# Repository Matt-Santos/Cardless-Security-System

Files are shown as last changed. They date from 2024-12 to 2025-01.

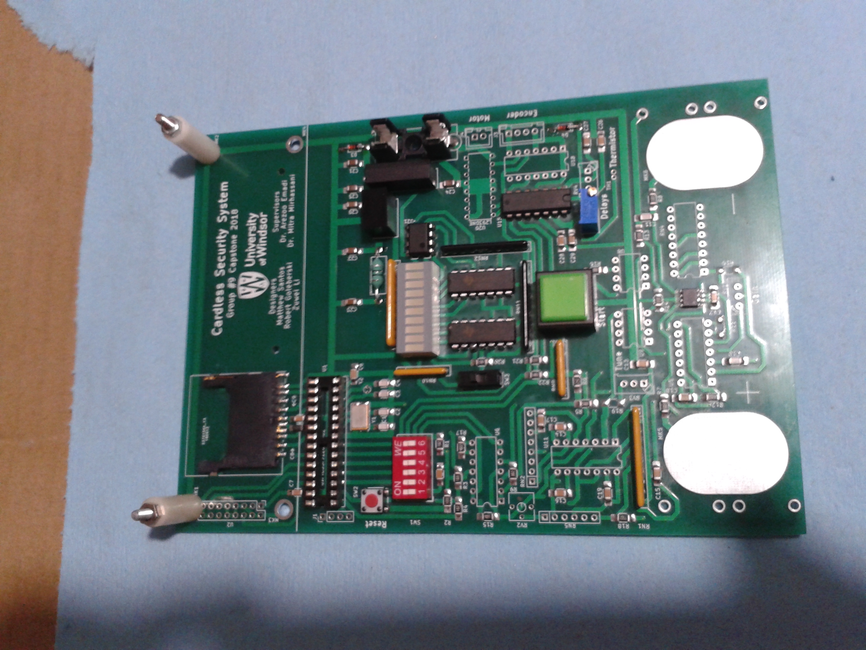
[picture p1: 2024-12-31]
documents/images/gallery/Partial Assembly 2.jpg

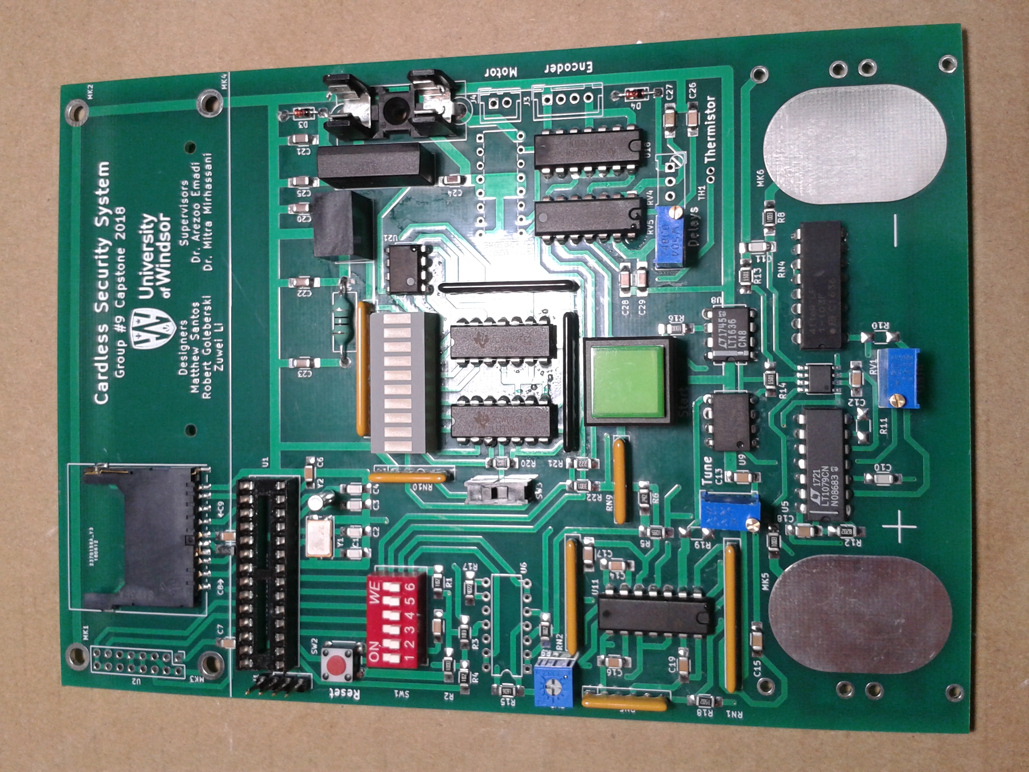
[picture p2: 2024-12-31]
documents/images/gallery/Partial Assembly.jpg

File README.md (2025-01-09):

# Cardless Security System
***
## Project Description
A **cardless security system** based on human **electro cardiogram (ECG) biometrics** that will be able to identify specified individuals, assess their authorization privileges and subsequently permit or deny access to
restricted areas. The entry regulation method is a custom designed electronic door locking
mechanism. Device is includes additional security features to prevent unauthorized entry. The unit
itself is battery operated with audio and visual indicators used to denote various system states.

## Goals and Objectives
1) Differentiate between individuals based on personal ECG signals
2) A secure mechanical locking system driven by an electric motor
## Brief Background
Most biometric identification devices currently in use throughout the world rely on either facial,
fingerprint, retina, or voice recognition systems. All of these authentication methods have been shown to
produce unique signatures that remain relatively consistent over time and are difficult to emulate with
the notable exception of voice based systems. Although obviously less secure the appeal of audio
biometric systems is driven primarily by its substantially lower implementation costs as opposed to the
other metrics which require sophisticated vision hardware. This desire for inexpensive biometric devices
has driven the search for alternative unique human signatures. Over the last few years electrocardiogram
(ECG) based recognition has shown potential. One of the advantages of this metric include the fact it is
an internal signal which is highly subject to personal health and mental state and is thus difficult to
procure from unwilling or deceased individuals. It is also fairly inexpensive to both capture and process
the ECG signals leading to a very high overall desirability. Research into this field is still being
conducted and very few viable commercial products are currently available.

## Final Result
An enclosed printed circuit board mounted alongside a custom electronic door locking mechanism.
The board is to include a built-in ECG acquisition system, audio and visual status indicators, as well as
the internal processing power required to perform biometric identification.

## Timeline
See [Gantt Chart](/documents/reports/Proposal/ProjectSchedule.pdf)

# Software Listing
* Git
* KiCAD
* GanttProject
* Latex (MiKTeX)
* Matlab (Octave)
* LTSpice

# Team Members
* Matthew Santos
* Robert Goleberski
* Zuwei Li
# Supervisors
* Dr. Emadi
* Dr. Mirhassani

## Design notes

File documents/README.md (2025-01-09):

This cardless security system leverages human electrocardiogram (ECG) biometrics for authentication. It features an integrated printed circuit board (PCB) paired with a custom electronic door locking mechanism. The PCB houses an ECG acquisition system, audio/visual status indicators, and sufficient processing power to perform biometric identification. When an ECG credential is submitted, the system extracts 27 distinct fingerprint variables from the signal. These variables are then processed by a support vector machine (SVM) to generate a score that indicates the similarity between the submitted ECG and the authenticated user's ECG data. The SVM is trained on a comprehensive database of ECG signals, with system reliability being highly dependent on the quality and quantity of the training data used.

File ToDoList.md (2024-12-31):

# Overall Progress:
## General
- [x] Assemble group and discus the project
- [x] Get the project approved
- [x] Generate Block Schematic
- [x] Power Circuit
- [x] Sensor Circuit
- [x] MPU Circuit
- [x] Signal Processing Code
- [x] Design Overall Circuit Schematic
- [x] Complete the Progress Report
- [x] Prepare Progress Report Presentation
- [x] Decide on Parts and Perform Layout
- [x] Build the Prototype
- [x] Test the Prototype
- [x] Complete the Final Report
- [x] Finalize Project Presentation
## Simulation Work (Matlab/Octave)
- [x] Obtain Small Library of Sample Data
- [x] Create Script to Perform Initial Filtering (Preprocessing)
- [x] Create Script to Perform Feature Extraction
- [x] Create Script for Biometric Support Vector Machine
## Digital Signal Processing
- [x] Determine Resolution and Sample Rate
- [x] Design the Preprocessing Filters
- [x] Design the Feature Extraction Transfer Functions
- [x] Realize All DSP Filters
- [x] Integrate Into MicroController
## MicroController Programing
- [x] Configure Setup
- [x] Setup Start Button Trigger
- [x] Setup ADC Sampling
- [x] Create Interrupt Routines
- [x] Write Preprocessing Procedure
- [x] Write Feature Extraction Procedure/Code
- [x] Write Support Vector Machine
- [x] Write Authorize Output Trigger
- [x] Create Functions for LCD Control
- [x] Create Functions for SD-Card Control
- [x] Add LCD Functionality
- [x] Add SD-Card Functionality
- [ ] Convert Key Variables to SD-Card Reads (Externalize Control)

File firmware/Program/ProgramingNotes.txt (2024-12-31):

//Important MPU Notes for Report

//General Details
- MPU setup to run at 40MHz through use of a PLL
- Uses a Status Register to Monitor Progress
- Currently Using Fixed Point Arithmetic!
- Takes approximately 6 cycles (150ns) per fractional multiplication

//ADC1 Setup
- Uses Simultaneous Sampling
- Uses DMA for quick transferring to SRAM
- Conversion Triggered by Timer3 Compare Event
- Data Transfered in a Ping-Pong Mode with Two alternating Output Buffers
- Measurement Accuracy is 10bit giving +/- 3mV at [0V,3V] limits
- SampleRate is Easily Adjustable between 10Hz and 625kHz
- Temperature is currently only sampled once per DMA block

//Temperature Averaging
- Performed using the DSP Engine
- Calculation accuracy of +/- 0.04mV
- Each Sample Takes 10 cycles (250ns) to process

//Preprocessing Setup
-

//Notes for Report
- Greatest Challenge: (Conversion to Fixed Point Arithmetic)
    - You see in Matlab/Octave you have a supercomputer so you just use floats for everything
    the problem is that float math is really slow on a microcontroller and it was not until
    after I designed the algorithm that I realized this. I essentially had to rip apart large
    sections and completely redesign them using one of the most confusing data types I have had
    the horror of working with ... Fixed point math...

//Things to do Before Trying on Chip Itself
- uncomment sleep and remove forced start button press
- uncomment delay after start button press
- Ensure SampleRate = 500
- Set ECGLength = 2560
- Set DMA0BufferSize = 32

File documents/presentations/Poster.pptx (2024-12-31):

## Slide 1

Cardless Security System
Using Electrocardiogram Biometric Identification
Faculty of Engineering Dept. Electrical and Computer Engineering
Group 9 – Zuwei Li, Matthew Santos, Robert Goleberski
Advisors: Dr. Arezoo Emadi, Dr. Mitra Mirhassani
Capstone Project 2018

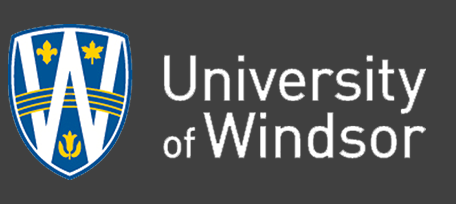
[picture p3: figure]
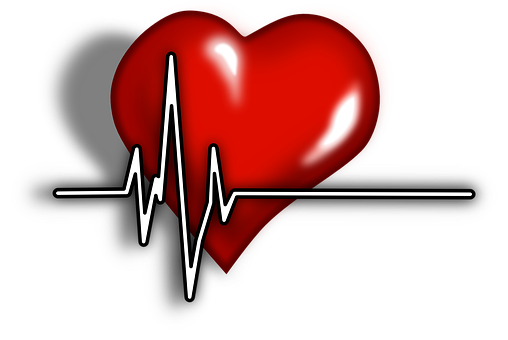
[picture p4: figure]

Final Prototype

Motivation

Current methods of biometric identification include voice analysis, retina scans, face recognition and the widely popular fingerprint system. The current success of the fingerprint method is owed to its compromise between the level of security offered and the cost of implementation. The remaining methods are still applicable however they generally lean towards either extreme and thus remain niche markets. There is however a new contender entering the industry which also offers a balanced approach. This new system which is still undergoing research, utilizes the measurement of the internal heart signal through an electrocardiogram in an attempt to distinguish individuals. Being an internal signal offers a wide array of benefits including reduced public exposure as well as the inability to modify the access token. Results continue to look promising however there are still many obstacles to overcome before it becomes the new standard.

Biometric Algorithm

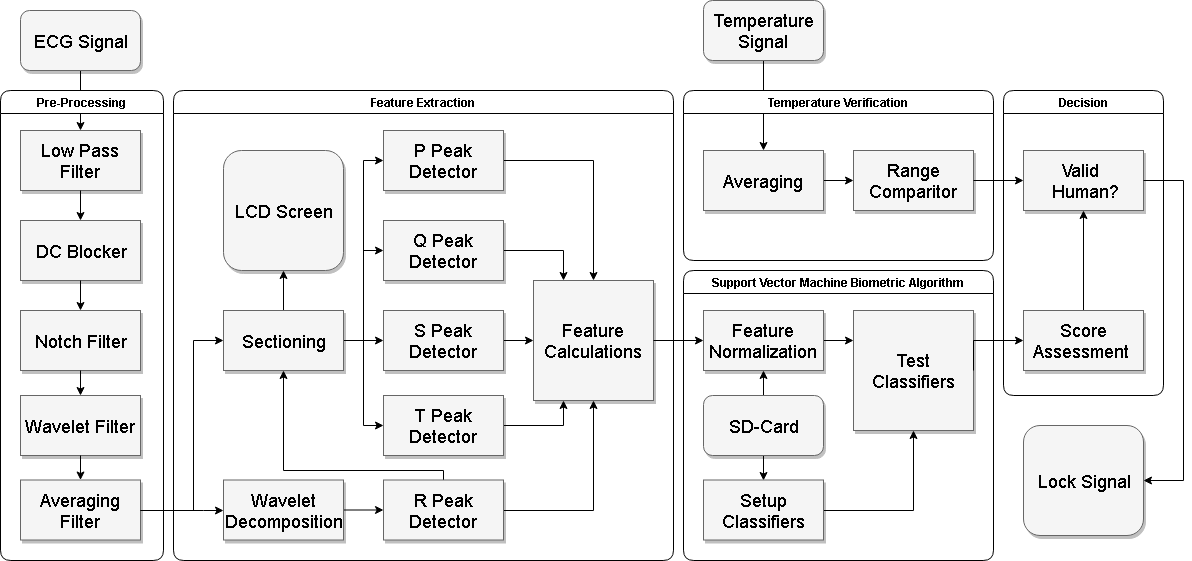
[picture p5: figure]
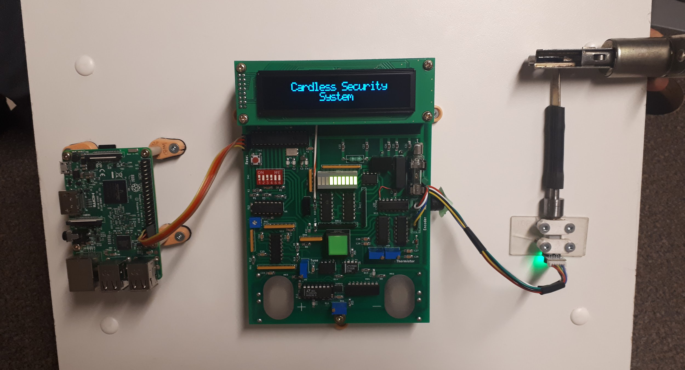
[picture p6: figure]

Experiment Results

Introduction

The aim of this project was to develop a cardless security system based on the principle of ECG biometrics. To facilitate future investments in the field the project was tailored towards the development of a marketable product. In order to accomplish this a more unobtrusive method for ECG acquisition was required as the standard 12 lead system is impractical for everyday use. Instead a two finger based ECG measurement system was proposed using inexpensive dry contact electrodes. As this measurement methodology degrades signal quality the analysis procedure had to be heavily refined through the use of onboard digital signal processing. The biometric algorithm itself also had to be constructed from scratch and was centered around the use of machine learning, more specifically support vector machines. After being processed the resulting biometric determination is then used in conjunction with information gathered from a secondary temperature sensor in order further validate the individual as human and actuate the locking mechanism.

System Requirements

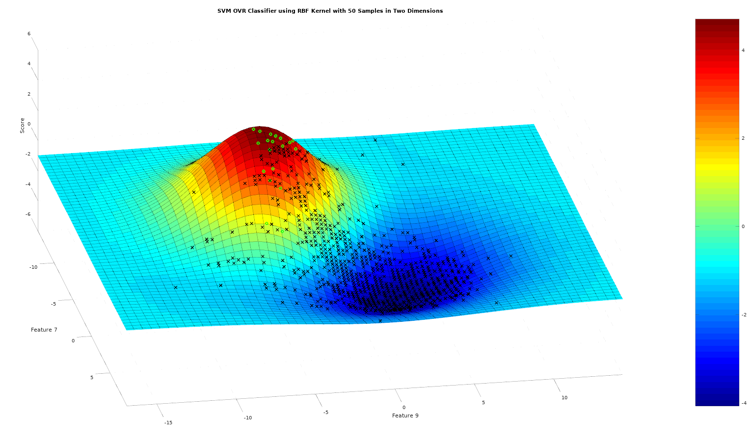
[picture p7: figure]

System Architecture

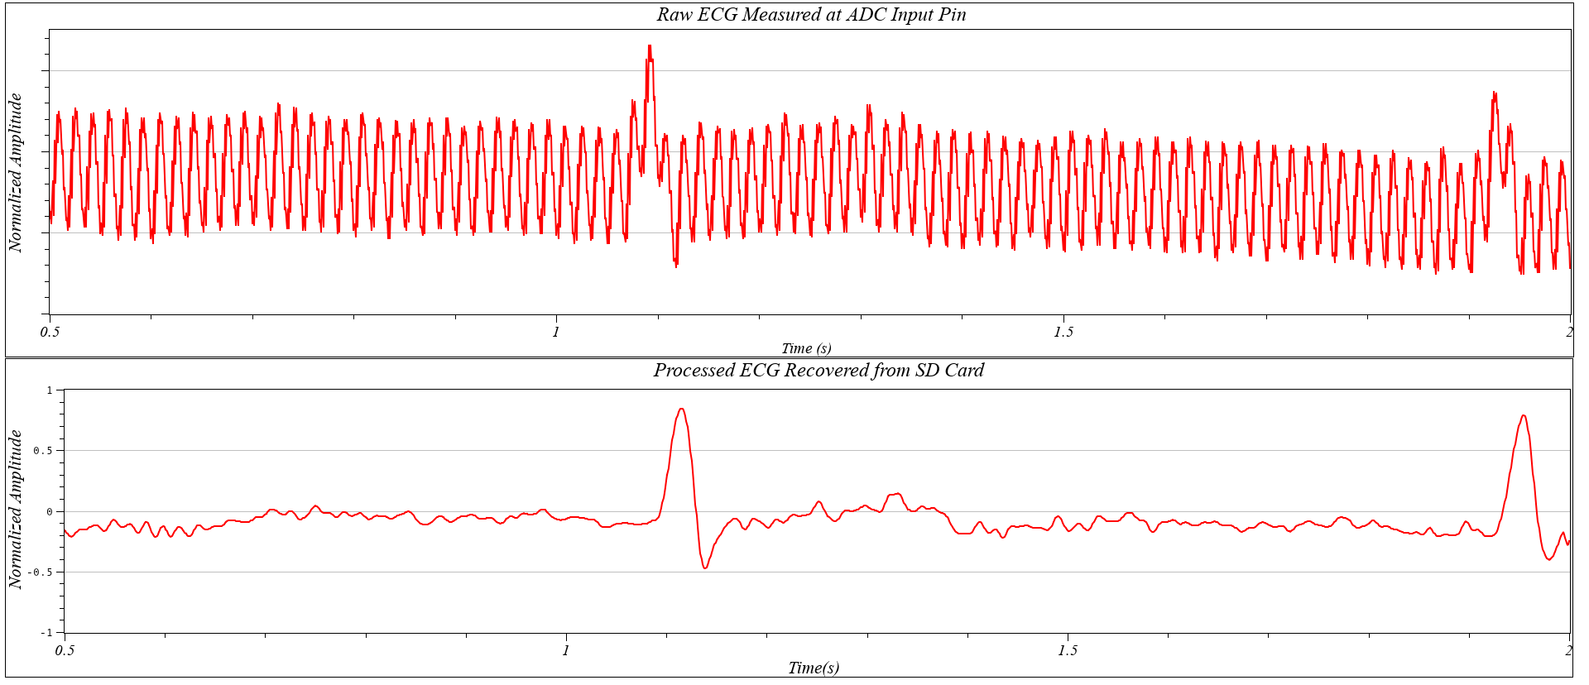
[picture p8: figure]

Future Work

- Continue to refine the biometric algorithm to improve accuracy
- Transition to a surface mount design for smaller form factor
- Perform a research study to accurately determine success rate

Acknowledgements

- Supervisors: Dr. Arezoo Emadi & Dr. Mitra Mirhassani
- Special Thanks: Frank Cichello, Dr. Behnam Shahrrava,

- System must differentiate between individuals based on electrocardiogram signals
- A completely embedded design with a black box emphasis for added security
- Incorporate a secure mechanical locking system driven by an electric motor
- An affordable solution, specifically an initial prototype budget of less than $350
- Present audio and visual indicators regarding the status of execution

References

- Lourenco, Andre & Plácido da Silva, Hugo & Santos, Daniel & Fred, Ana. (2011). Towards a Finger based ECG Biometric System
- Lugovaya T.S. (2005). Biometric human identification based on electrocardiogram

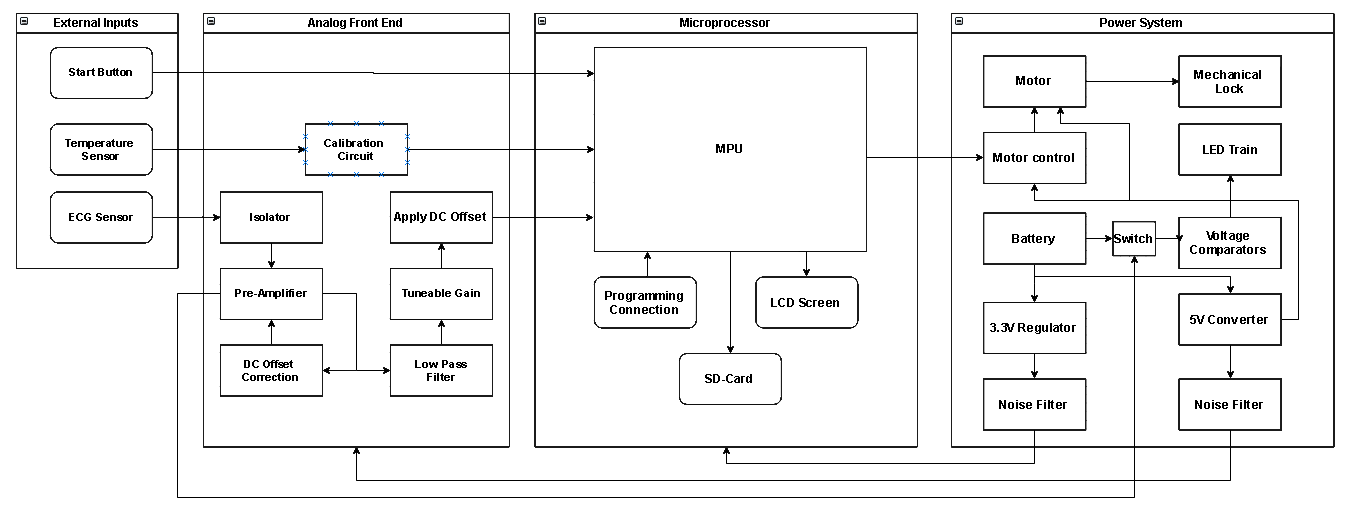
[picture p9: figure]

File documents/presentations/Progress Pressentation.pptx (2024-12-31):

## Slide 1

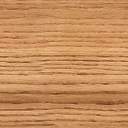
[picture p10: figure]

Cardless Security System

Robert Goleberski
Matthew Santos
Zuwei Li

## The Problem

- Current Solutions:
-Iris, Voice, Fingerprint, Facial
- Relatively easy to obtain identifiers
- Many locks require an access token or key
- Modern Biometric Locks are expensive

## The Solution

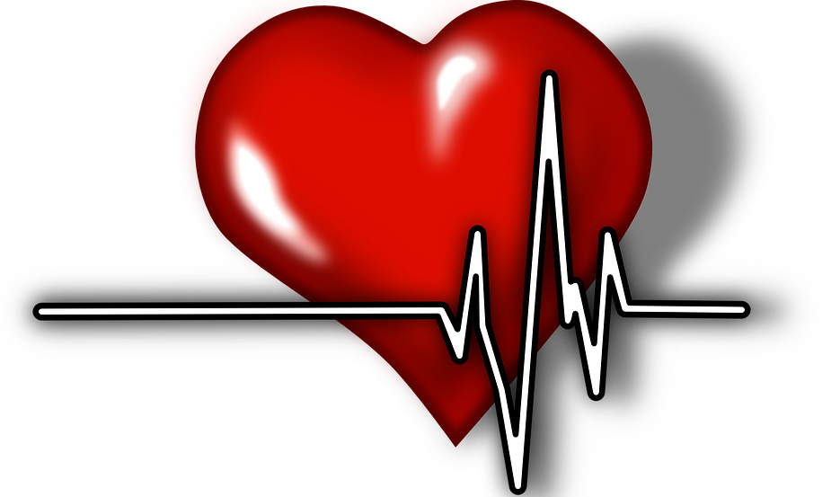
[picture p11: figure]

- Not easily stolen
- Cheap to measure
- Reliable?

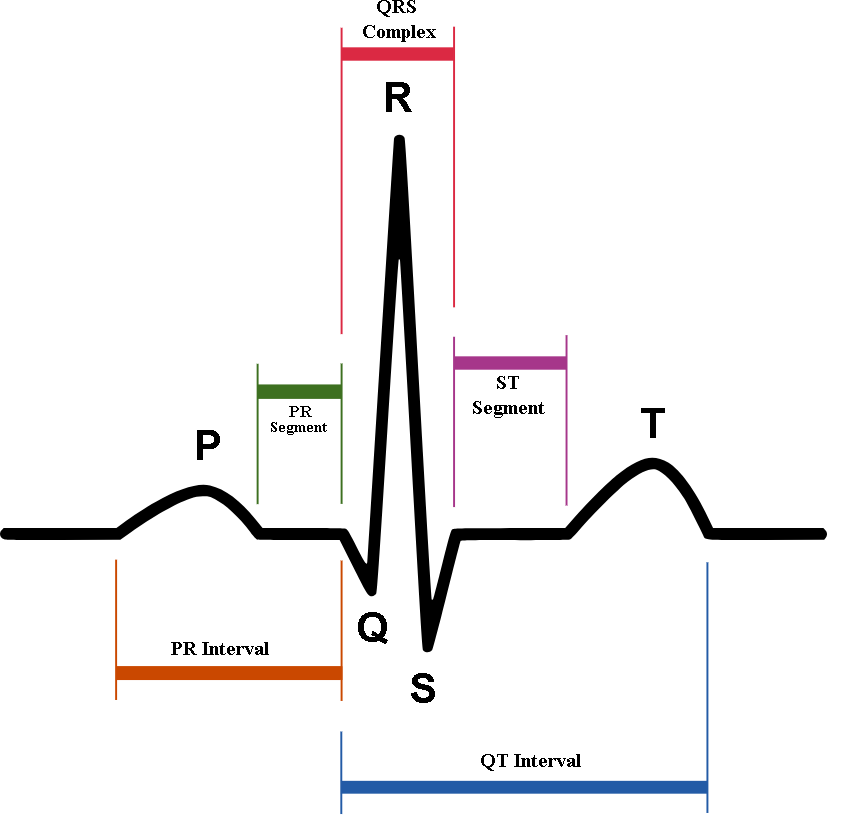
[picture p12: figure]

## ECG Measurement

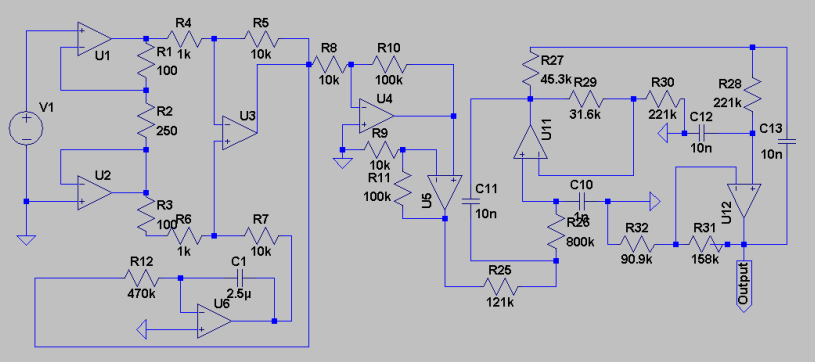
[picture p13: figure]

- Analog front end ECG circuit

## Amplification

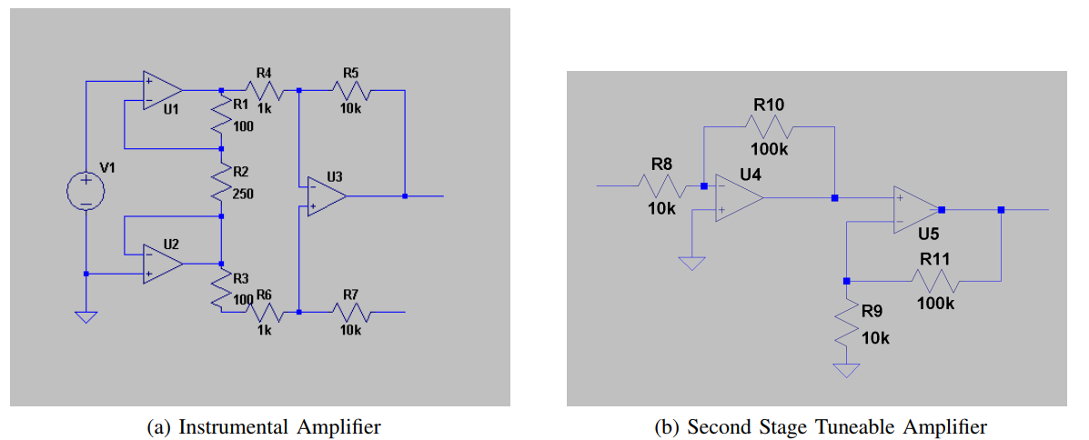
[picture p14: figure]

## Noise Considerations

- Baseline drift
- Sixty hertz hum
- High frequency noise
  - Micro muscle spasms

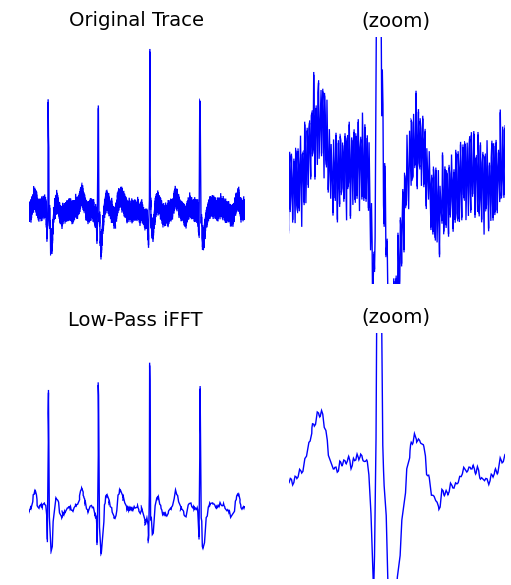
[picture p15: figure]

## Filter

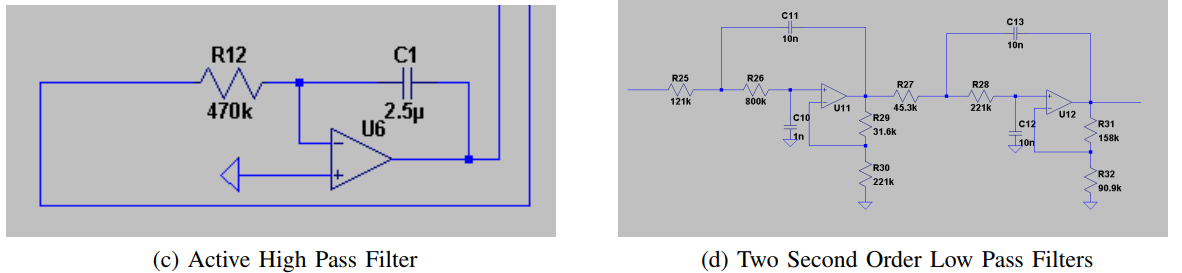
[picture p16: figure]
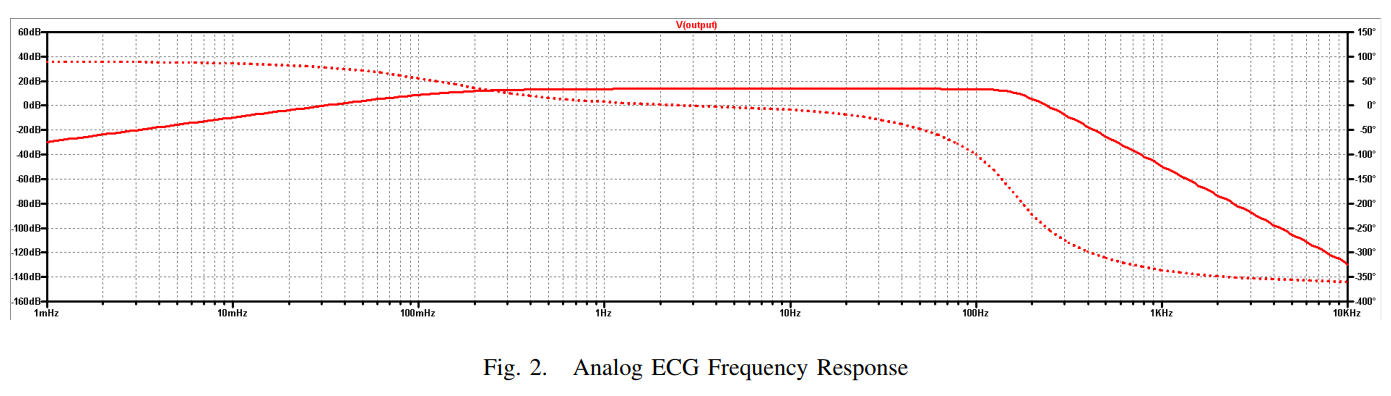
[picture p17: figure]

## Biometric Algorithm

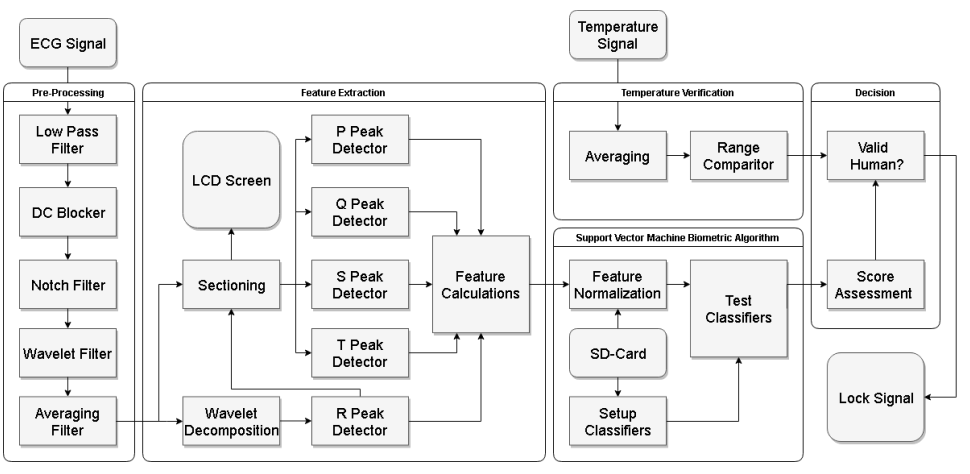
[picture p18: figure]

## Offload Processing

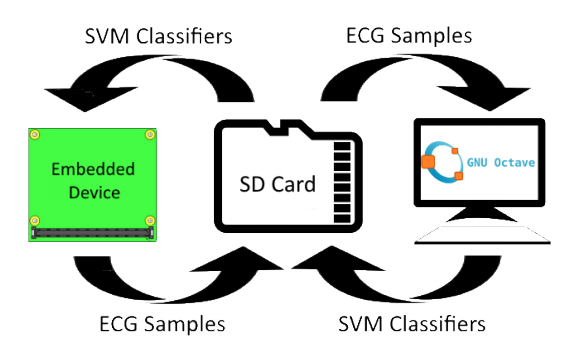
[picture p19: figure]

## Results of Testing

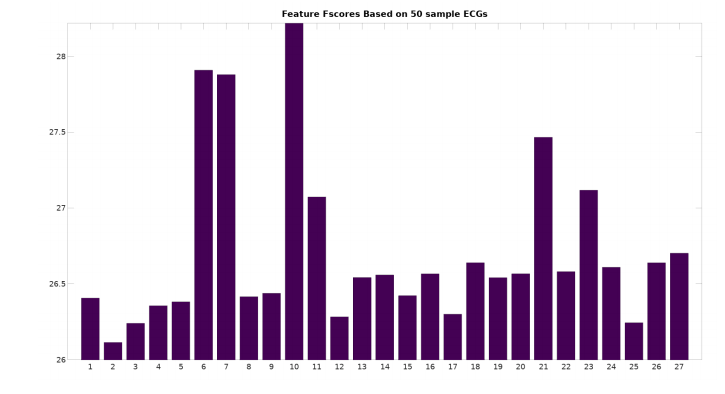
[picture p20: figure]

## Results of Testing

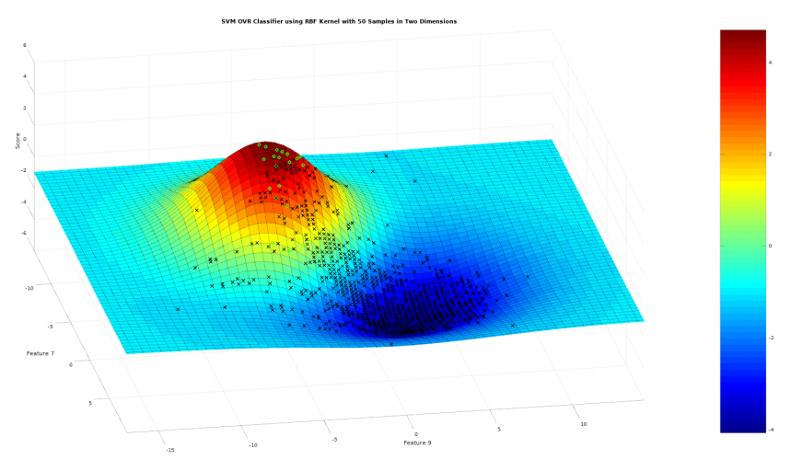
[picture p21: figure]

## Powering the System

- Powered through batteries
  - AA batteries due to size convenience
- Regulator to protect the circuits supplied
  - Analog front end and Microprocessor

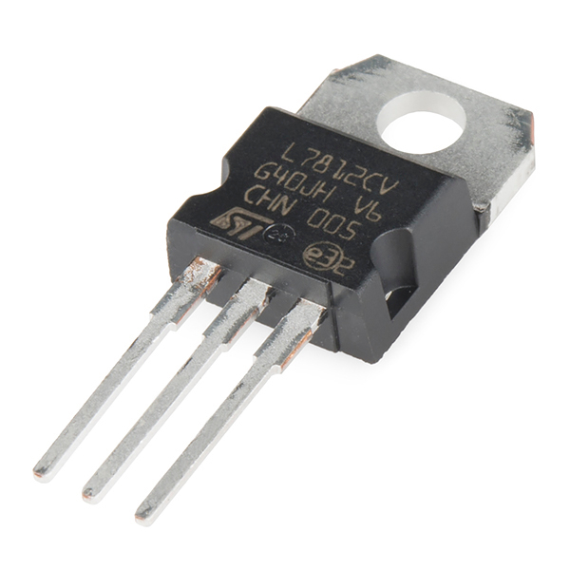
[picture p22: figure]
Image result for electronic regulator
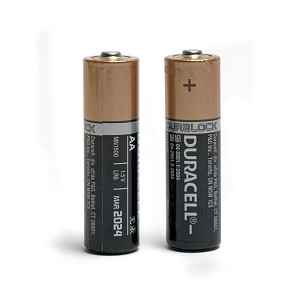
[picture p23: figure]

## Motor Controller

- Locking will take place with a deadbolt
- Deadbolt to be moved by a servo motor
- This motor is controlled through PWM

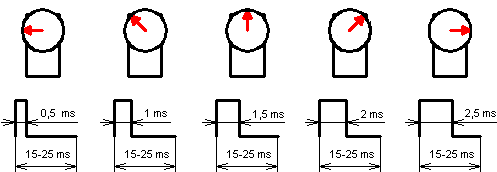
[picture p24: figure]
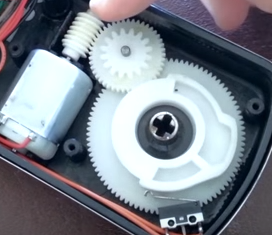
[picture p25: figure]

## Voltage Indicator

- Consists of LED’s and resistors
  - Push button to conserve power
- Colour coded to indicate charge of batteries

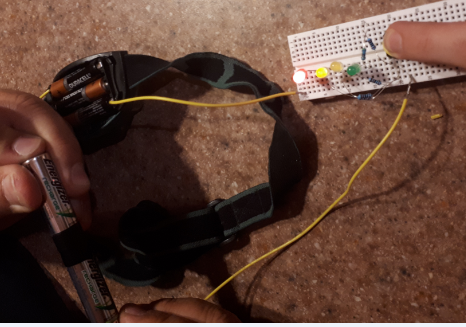
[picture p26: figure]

## Next Steps

- Select and order parts
- Build and test circuits
- Build prototype (PCB)
- Debugging
- Gather samples
- Document findings

Image result for PCB

## Summary

- Completed:
  - Front end ECG processing
  - Bioalgorithm
  - Power charging and monitoring system
- In Progress
  - Part selection
  - Testing and construction
- Estimated time of completion : July 27th

## References

- http://www.milemarkerbrewing.com/heart-attacks-and-defibrillators/

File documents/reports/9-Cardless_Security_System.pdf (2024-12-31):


# Cardless Security System

88-400-01: CAPSTONE DESIGN PROJECT

PROGRESS REPORT

JANUARY TO APRIL 2018

## Department of Computer and Electrical Engineering

### Attention to Dr. Arezoo EMADI and Dr. Mitra MIRHASSANI

### May 9th,2018

CONTENTS

I | Progress Summary | 2
II | Introduction | 2
II-A | Project Description | | 2
II-B | Project Design Objectives | | 2
III | Work Completed | 3
III-A | Analog Front End | | 3
III-B | Microprocessor | | 4
III-C | Power Distribution and Lock System | | 5
IV | Work Scheduled | 6
V | Outstanding Issues | 6
VI | Schedule Changes | 6
Appendix A: Revised Project Schedule | 7
Appendix B: ECG Analog Front End Schematic | 8
Appendix C: Biometric Algorithm Test | 9
Appendix D: Microprocessor Schematic | 10
Appendix E: Power System Schematic | 11

# Cardless Security System

Robert Goleberski, Student Member, IEEE, Zuwei Li, Student Member, IEEE, and Matthew Santos, Student Member, IEEE

I. PROGRESS SUMMARY
At this time the project has reached the halfway mark and although significant progress has been made, presently development is approximately two weeks behind schedule. The need to perform several design iterations has pushed part selection back. In order to reconcile lost time and prevent further delay an increased effort from the group members is required. A new schedule has been drafted with a tighter timeline which still reserves the month of July for testing. Presently the design of nearly all electric circuit sub-components is complete however part selection of in some areas is still underway and will need to be completed as soon as possible. Design of the biometric algorithm is also complete and has been shown to produce 94% accuracy. Implementation of this algorithm into microprocessor code is still ongoing and will likely be conducted alongside breadboard testing to aid in debugging.

II. INTRODUCTION
The purpose of this report is to outline the current state of progression on the cardless security system capstone project, describe the work remaining and present an updated schedule. This report covers the period of time between initial selection of the project in January up until May 5th 2018 which represents roughly half of the allocated project timeframe. During this time design on various aspects have been completed and the transition towards selecting parts for a physical implementation is underway. Prior to the discussion on development situation, the following brief synopsis of the project and its associated design objectives is provided in order to provide context and reiterate expectations.
A. Project Description
The project entails the development of a cardless security system focused on electrocardiogram (ECG) biometrics which is capable of uniquely identifying an individual in order to discern their level of access. Regulation of this access is to be conducted using a secure mechanical locking system operated by a direct current motor. Additional features are to be included in order to further increase security and prevent unauthorized entry. The device is expected to be an embedded solution powered by batteries with audio and visual indicators used to denote various system states.
B. Project Design Objectives
1) Differentiate between individuals based on electrocardiogram signals
2) Develop a secure mechanical locking system driven by an electric motor

III. WORK COMPLETED
Development has been separated into three main sub-projects. These sub-projects include the analog front end, the microprocessor, and the power system. In order to facilitate perception of progress a block diagram illustrating these sub-projects and their composition is presented in Figure 1. The subsequent sections are used to summarize the current status of these three areas.


Fig. 1. Overall Design Block Diagram

A. Analog Front End
This sub-project is responsible for providing the interface to and refinement of the real world signals before directing them to the microcontroller for acquisition and processing. At present the design and simulation of the ECG line to the microprocessor has been completed although part selection is still being conducted. The necessary theory required for the temperature sensor calibration circuit has been completed but its final design values are subject to sensor selection which is also ongoing.
As the measurement of real signals is always accompanied by noise preliminary analog filters were strategically implemented in order extract clear ECG signals. At present the analog ECG processing consists of an instrumentation amplifier which is used for its low noise gain and isolation. A first order high-pass filter configured to provide reference feedback to the instrumental amplifier for low frequency noise removal and lastly a pair of 2nd order low-pass filters which have been preset to a cutoff frequency of 100Hz. Simulation of this configuration has demonstrated excellent results as seen in Figure 2 which illustrates the frequency response of the ECG front end. From the figure it is clearly seen that the region of interest from 500mHz to 100Hz experiences an undistorted gain of approximately 20dB with first order falloff to the left and second order to the right.


Fig. 2. Analog ECG Frequency Response

Additional consideration was placed into correctly positioning the ECG output signal in the 0V to 3.3V region required by the microcontroller’s analog to digital converter. This was done by utilizing a potentiometer tuneable secondary gain stage which also serves to apply the required DC offset. These front end components are individually presented in Figure 3 with the complete design illustrated in Appendix B.


(a) Instrumental Amplifier | (b) Second Stage Tuneable Amplifier


(c) Active High Pass Filter | (d) Two Second Order Low Pass Filters

Fig. 3. Analog Front End Components

B. Microprocessor
A large majority of the assessment period was dedicated to the design and refinement of the biometric algorithm responsible for distinguishing an individual heart signal. A complete overview of the algorithm at present is illustrated in Figure 4. The computation consists of filtering the ECG signal using a series of digital filters followed by a custom feature extraction procedure which generates the primary test vector.


Fig. 4. Microprocessor Biometric Check Procedure

A support vector machine based classifier was employed as it offered more flexibility and was also more intuitive. As predicted while the application of support vectors was straight forward the amount of processing required to form said vectors exceeded the capabilities of most conventional microprocessors. Thus offloading of this task was required and the procedure for doing so takes advantage of the micro-SD card for the transfer medium as illustrated in Figure 5.


Fig. 5. Data Transfer Concept

At this time design of the algorithm itself is considered to be complete. It utilizes a total of 27 features to employ a one versus rest assessment on each individual included in the database taking advantage of the radial basis function kernel for separation. Utilizing a public collection of prerecorded ECGs the algorithm was extensively tested in computer simulations and successfully distinguished 47 out of the 50 individuals included in the database while also refusing an additional 10 who were not. Thus at present the success rate is estimated to be 94% with no false positives. In order to provide additional insight into the level of accuracy two additional figures are included in Appendix C which illustrate feature distinguishability levels and the capability of the radial basis function to isolate particular individuals across two features. Following algorithm design the dsPIC33FJ128GP802 by Microchip was selected to be the central processor for this project for its low cost and built in digital signal processing enhancements which allow for bulk multiplication and addition operations. The completed microprocessor and peripheral schematic is illustrated in Appendix D along with several notes on layout considerations. Based of rough calculations it is estimated that utilizing this microcontroller with a sampling time of 20 seconds and a database consisting of 50 people the assessment can be completed in five minutes. While reduction of this duration is possible it would require either a reduction in database capacity or identification accuracy.

C. Power Distribution and Lock System
The first issue confronted in this part of the project was powering the microprocessor. The supply line to power the selected microprocessor required a stable voltage of 3.3V with a peak current of 200mA. This was easily obtained with a simple buck-converter and power generated through D type batteries which were selected for their high ampere hour rating. A battery monitoring circuit was designed utilizing different colour light emitting diodes (LEDs) to indicate the energy level remaining. The monitor itself is to be push button activated in order to further conserve power.
The next task was designing the control for the lock. Initial design plans utilized a solenoid that would lock a strike keeping the door closed. The idea being once the signal from the microcontroller was applied a relay would activate the solenoid and the door could be opened. This was deemed too simple and so instead a deadbolt mechanism was proposed. In order to control the deadbolt a motor is to be utilized. It will be controlled using pulse width modulation coming from the microprocessor. The motor will either be a servo motor which can be controlled simply by PWM or a DC motor that would require a motor driver component. In addition there will also be a magnetic reed switch installed on the door and connected to the microprocessor to aid with positioning control of the deadbolt. In order to open the lock from inside a push-button connected to the microprocessor will be used to inform the processor to move the open the door. At this time the circuit design has been completed and roughly half of the required parts have been selected. A complete overview of the power system is presented in Appendix E. Physical testing of the battery monitor circuit was performed using remnants of an older project and was shown to behave as expected.

IV. WORK SCHEDULED
Progress has been made on the bulk of the design task but several sections still require additional work before implementation can begin. For the analog front end the sensors need to be selected along with the remainder of components and the calibration circuit for the temperature sensor suitably updated. Similarly the remainder of the components required for the power system must be chosen and additional consideration must be placed into the design of the mechanical locking mechanism and power line to the analog front end. At this time while the biometric algorithm has been designed it still needs to be integrated into microprocessor code and progress on this front is still ongoing.
Following the completion of the aforementioned tasks the procurement of the required parts can begin and breadboard testing of the various sub-sections started. Following successful verification a complete printed circuit board layout is to be generated and the final product constructed.
V. OUTSTANDING ISSUES
Although algorithm tests thus far have made use of public ECG signals said data was gathered using a different apparatus and thus will likely exhibit discrepancies from the utilized setup. This would lead to increased error in support vector classifications and could produce erroneous results. The creation of a database obtained utilizing the device itself would serve to eliminate this problem however this is not a trivial affair. As the sampling of student information that could be considered personally identifying raises ethical concerns the Research and Ethics Board (REB) on campus was contacted and consulted about how to handle the situation. An insight into the acceptable methods for gathering research data was achieved and steps are being taken to obtain REB approval. The process is lengthy and will require some level of assistance from the project supervisor. In addition permission will need to be sought out for the sending of a departmental email requesting willing participants in an independent manner. The goal is to have collected all the information needed to submit a proposal to the REB by the middle of May after which it is expected to have sanctioned sampling begin in mid June.

VI. SCHEDULE CHANGES
Modifications to the proposed schedule were required in order to allocate additional time for revising the initial designs and performing part selection. A revised schedule is proposed and is presented in Appendix A illustrating the current level of progress and restructuring past tasks to more closely resemble work done. In addition a new section dedicated to the breadboard testing of individual sub-projects prior to prototype assembly was added. Through the addition of this section it is hoped that any design issues can be eliminated prior to pcb manufacturing.
The primary goal of completing the overall prototype before the start of July remains unaltered, thus continuing to reserve a whole month of time for troubleshooting and testing.

APPENDIX A
REVISED PROJECT SCHEDULE


APPENDIX B
ECG ANALOG FRONT END SCHEMATIC


APPENDIX C
BIOMETRIC ALGORITHM TEST

Fig. 6. Relative Feature Distinguishability through Fscore

Fig. 7. Two Dimensional Feature Classification Example


D Date: KiCad E.D.A. kicad (2017-12-24 revision 570866557)-makepkg Rev: Size: A4

15p Authorize Start CD/DAT3 1 CMD 2 VSS 3 VDD 4 CLK 5 VSS 6 DAT0 7 DAT1 8 DAT2 9 CARD_DETECT 10 WRITE_PROTECT 11 SHELL1 12 SHELL2 13

OLED-100H016F MCLR 1 OSC2 10 SOSCI 11 SOSCO 12 VDD 13 PGED3 14 PGEC3 15 RP7 16 RP8 17 RP9 18 VSS 19 AN0/VREF+ 2 VCAP 20 RP10 21 RP11 22 RP12 23 RP13 24 RP14 25 RP15 26 AVSS 27 AVDD 28 AN1/VREF-/RA1 3 AN2/RP0 4 AN3/RP1 5 RP2 6 RP3 7 VSS 8 OSC1 9 U1

Id: 2/2 Sheet: /MPU/ File: MPU.sch Title:

LCD VDD 1 DB3 10 DB4 11 DB5 12 DB6 13 DB7 14 VSS 2 NC 3 RS 4 R/W 5 Enable 6 DB0

- Primary ECG Analog Input and Primary Digital Authorize Output

VDD Clock GND GND GND GND LCD_D4 LCD_D5 LCD_D6 LCD_D7

- Programing Header and DIP-Switch AUX Control

AUX1 AUX2 DSPIC33F MPU Design by Matthew Santos

- Two SPI Modules (SD-Card, LCD)

- Primary and Secondary Oscilators

- Almost all Pins on MPU are configurable in Code so some changes in Layout are possible (if needed)

AUX1 START AUX2 START AUX1 AUX2 START ECG

- Place all Decoupling Elements as close as possible to the MPU pins in layout (C1,C2,C3)

- AUX1, AUX2, and START can be disabled through SW1 if desired to reduce noise

- Consider Adding an Inductor between AVDD and VDD (manual section 2.2)

- Calculate Load Capaciters for Crystals wrt Crystal Datasheet

- Follow Advice of manual section 2.6 for oscilator layout

- Some Guides Recommend using Pullups for SD Cards

- SD Card and LCD Screen to operate in SPI Mode

- During Programing SW1-1 Required Open

ECG_Signal needs front end Protection from ESD

APPENDIX E
POWER SYSTEM SCHEMATIC


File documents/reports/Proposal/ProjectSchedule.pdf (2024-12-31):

Capstone Cardless Security System | Feb 2, 2018
University of Windsor | https://github.com/Matt-Santos/Capstone
Project manager | Arezoo Emadi
Project dates | Jan 4, 2018 - Aug 7, 2018
Completion | 9%
Tasks | 33
Resources | 4

Development of a Cardless Security System for Offices based on biometic ECG signals.

Name | End date
Planning | 2/25/18
Idea Selection | 1/8/18
Approval | 1/13/18
Proposal | 2/25/18
Gather Refrences | 1/30/18
Define Goals | 2/6/18
Establish Timeline | 2/6/18
Disscus Budget | 2/2/18
Generate Tasks | 2/11/18
Divide Tasks | 2/11/18
Approve Proposal | 2/24/18
Submit Proposal | 2/25/18
Circuit Schematic Design | 3/30/18
Generate Block Diagram | 2/16/18
Power System | 3/18/18
Sensor Circuitry | 3/18/18
DSP Processing | 3/18/18
Additional Features | 3/25/18
Finish Circuit Design | 3/30/18
Mechanical Design | 4/1/18
Prepare Progress Report | 4/5/18
Submit Progress Report | 4/6/18
Part Selection | 4/15/18
Simulation | 4/29/18
Project Verification | 5/3/18
PCB Layout | 5/16/18
Prototype Construction | 5/30/18
Capstone Cardless Security System | Feb 2, 2018
Tasks | 2

Name | End date
Testing | 6/30/18
Prep For Presentation | 8/6/18
Organize Presentation Materials | 7/7/18
Create Presentation Materials | 7/20/18
Practise Presentation | 7/31/18
Final Presentation | 8/6/18
Tasks | 3

Name | Default role
Arezoo Emadi | project manager
Matthew Santos | Student
Robert Golberski | Student
Zuwei Li | Student

## Resources

4

## Gantt Chart

Name; End date; Planning; Idea Selection; Approval; Proposal; Gather Refrences; Define Goals; Establish Timeline; Disscus Budget; Generate Tasks; Divide Tasks; Approve Proposal; Submit Proposal; Circuit Schematic Design; Generate Block Diagram; Power System; Sensor Circuitry; DSP Processing; Additional Features; Finish Circuit Design; Mechanical Design; Prepare Progress Report; Submit Progress Report; Part Selection; Simulation; Project Verification; PCB Layout; Prototype Construction; Testing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

## Resources Chart

6

Name | Default role
Arezoo Emadi | project mana...
Matthew Santos | Student
Robert Golberski | Student
Zuwei Li | Student
January | February | March | April | May | June | July | August

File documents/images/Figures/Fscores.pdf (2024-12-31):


1 2 3 4 5 6 7 8 9 10 11 12 13 14 15 16 17 18 19 20 21 22 23 24 25 26 27

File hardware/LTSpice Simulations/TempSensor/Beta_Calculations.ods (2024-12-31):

 | Celsius | Kelvin | Rx | Vout | C | K | Rx | Vo
Temp Max | 60 | 333.15 | 994.9 | 3.4 | 60 | 333 | 995 | 3.38121885633443
Temp Human | 37 | 310.15 | 2168.4 | 2.3 | 59 | 332 | 1027 | 3.34246440655223
Temp Min | -20 | 253.15 | 27519.9 | -0.9 | 58 | 331 | 1060 | 3.30286515144625
 |  |  |  |  | 57 | 330 | 1095 | 3.26241387018954
Beta Low | 0 | 273.15 |  |  | 56 | 329 | 1130 | 3.22110416589375
Beta High | 50 | 323.15 |  |  | 55 | 328 | 1168 | 3.17893053175808
Beta | 3500 |  |  |  | 54 | 327 | 1206 | 3.13588841878743
 |  |  |  |  | 53 | 326 | 1247 | 3.09197430485369
 | Rx | Kelvin |  |  | 52 | 325 | 1288 | 3.04718576484269
Nominal Resistance | 10000 | 273.15 |  |  | 51 | 324 | 1332 | 3.0015215415953
Upper Resistance | 1377.12243844074 | 323.15 |  |  | 50 | 323 | 1377 | 2.95498161731717
 |  |  |  |  | 49 | 322 | 1424 | 2.90756728509671
 |  |  |  |  | 48 | 321 | 1473 | 2.85928122013519
Dividing Resistor | 3000 |  |  |  | 47 | 320 | 1524 | 2.8101275502583
Vdd | 5 |  |  |  | 46 | 319 | 1577 | 2.76011192524331
Vee | -1.5 |  |  |  | 45 | 318 | 1633 | 2.70924158446276
 |  |  |  |  | 44 | 317 | 1690 | 2.65752542231354
 |  |  |  |  | 43 | 316 | 1750 | 2.60497405087032
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

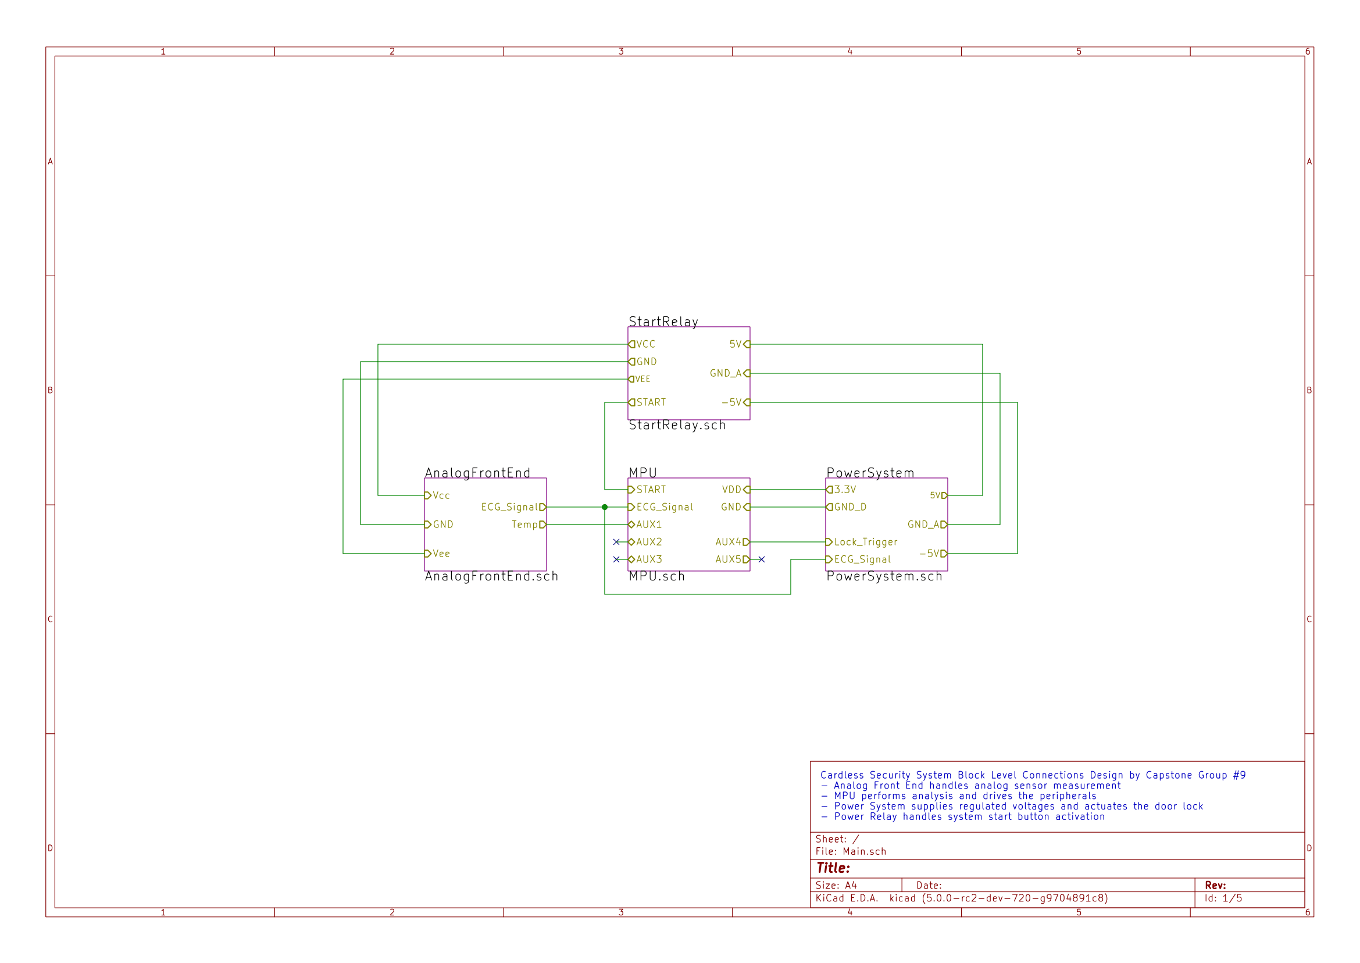
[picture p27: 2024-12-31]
documents/images/Figures/Circuit_Schematic-1.png

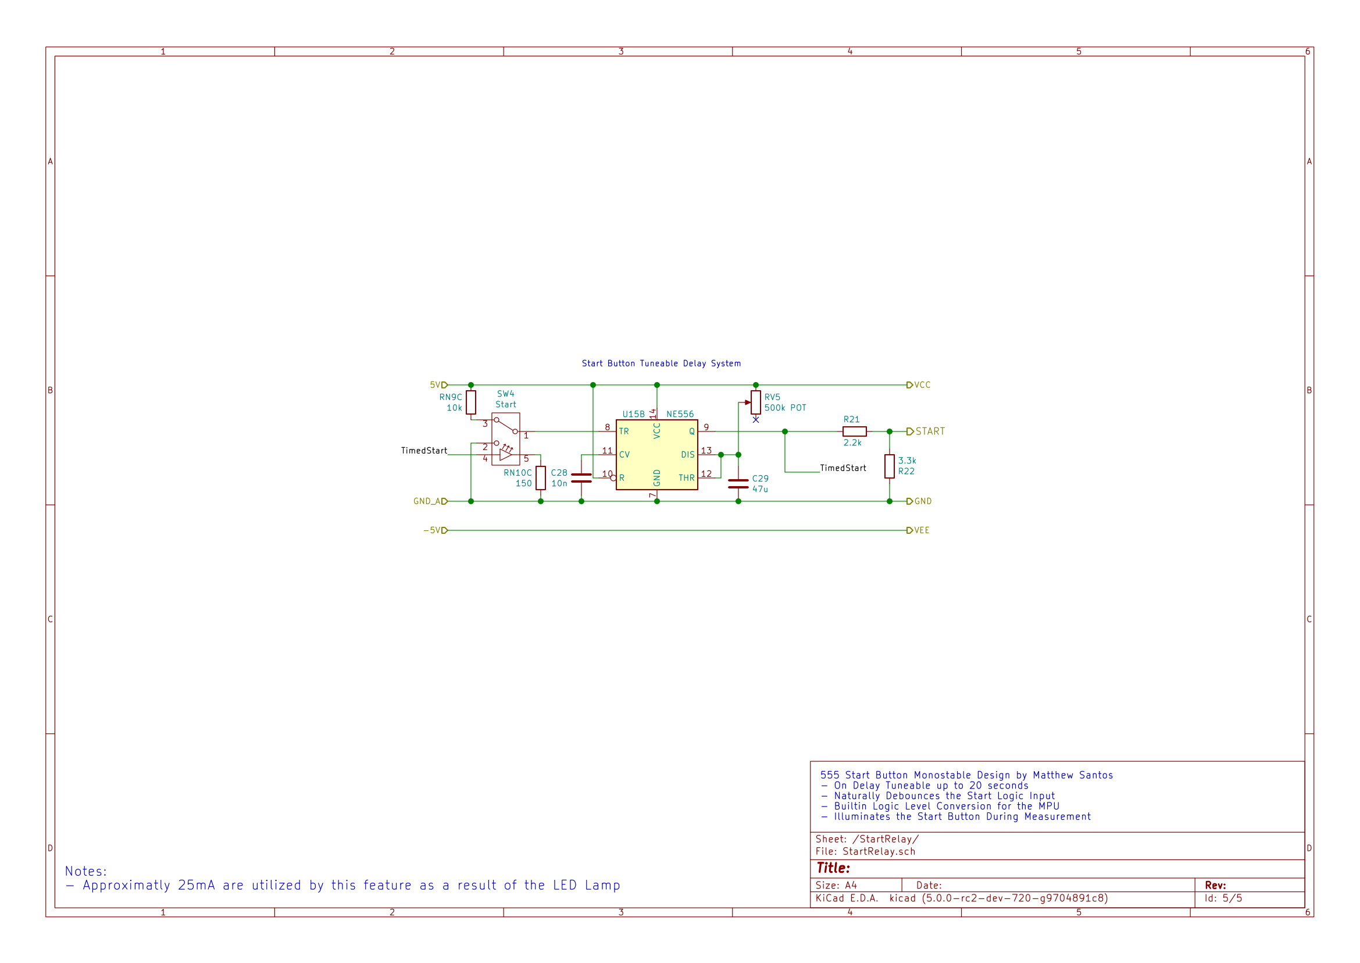
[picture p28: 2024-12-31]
documents/images/Figures/Circuit_Schematic-5.png

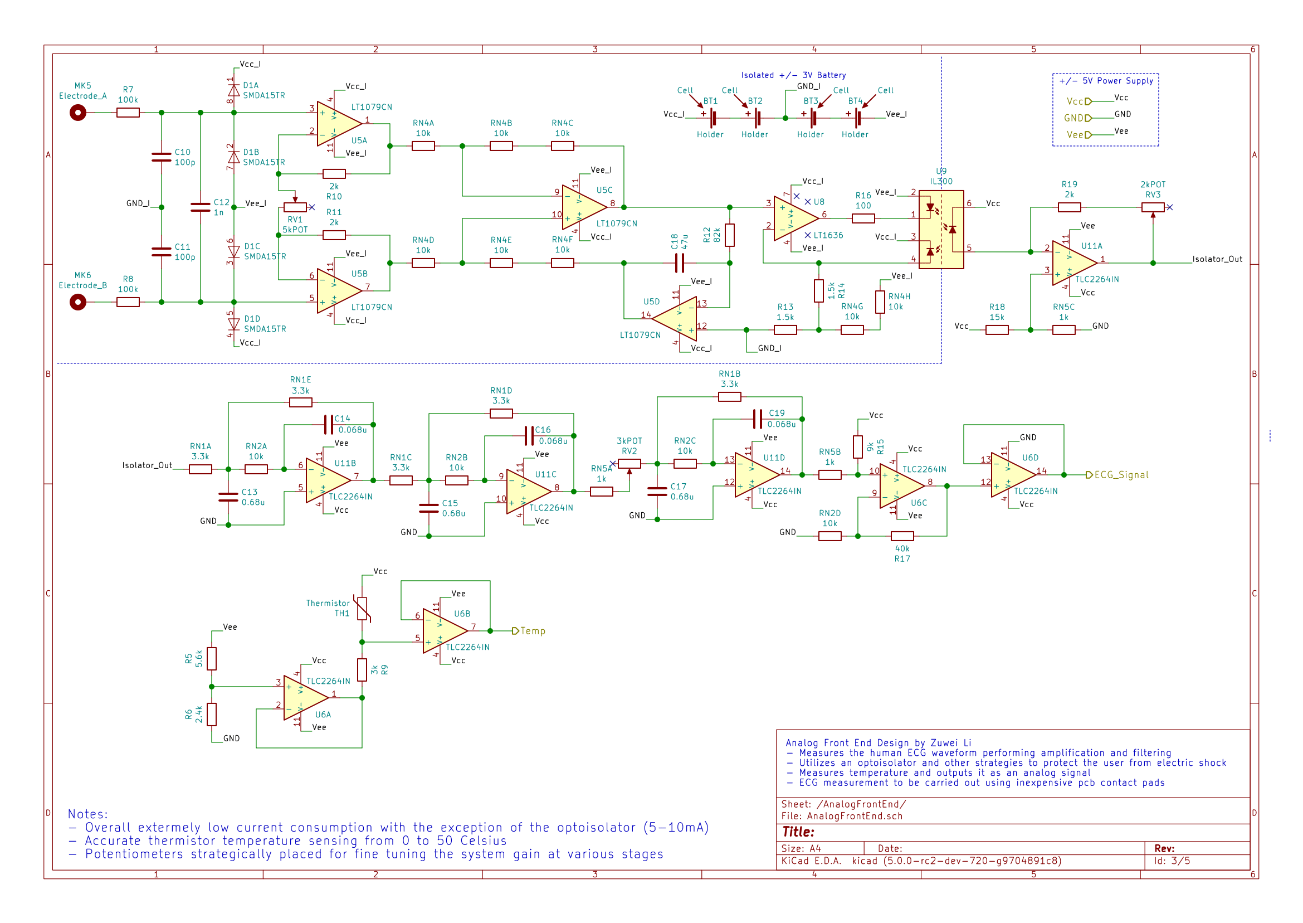
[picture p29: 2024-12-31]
documents/images/Figures/Circuit_Schematic-3.png

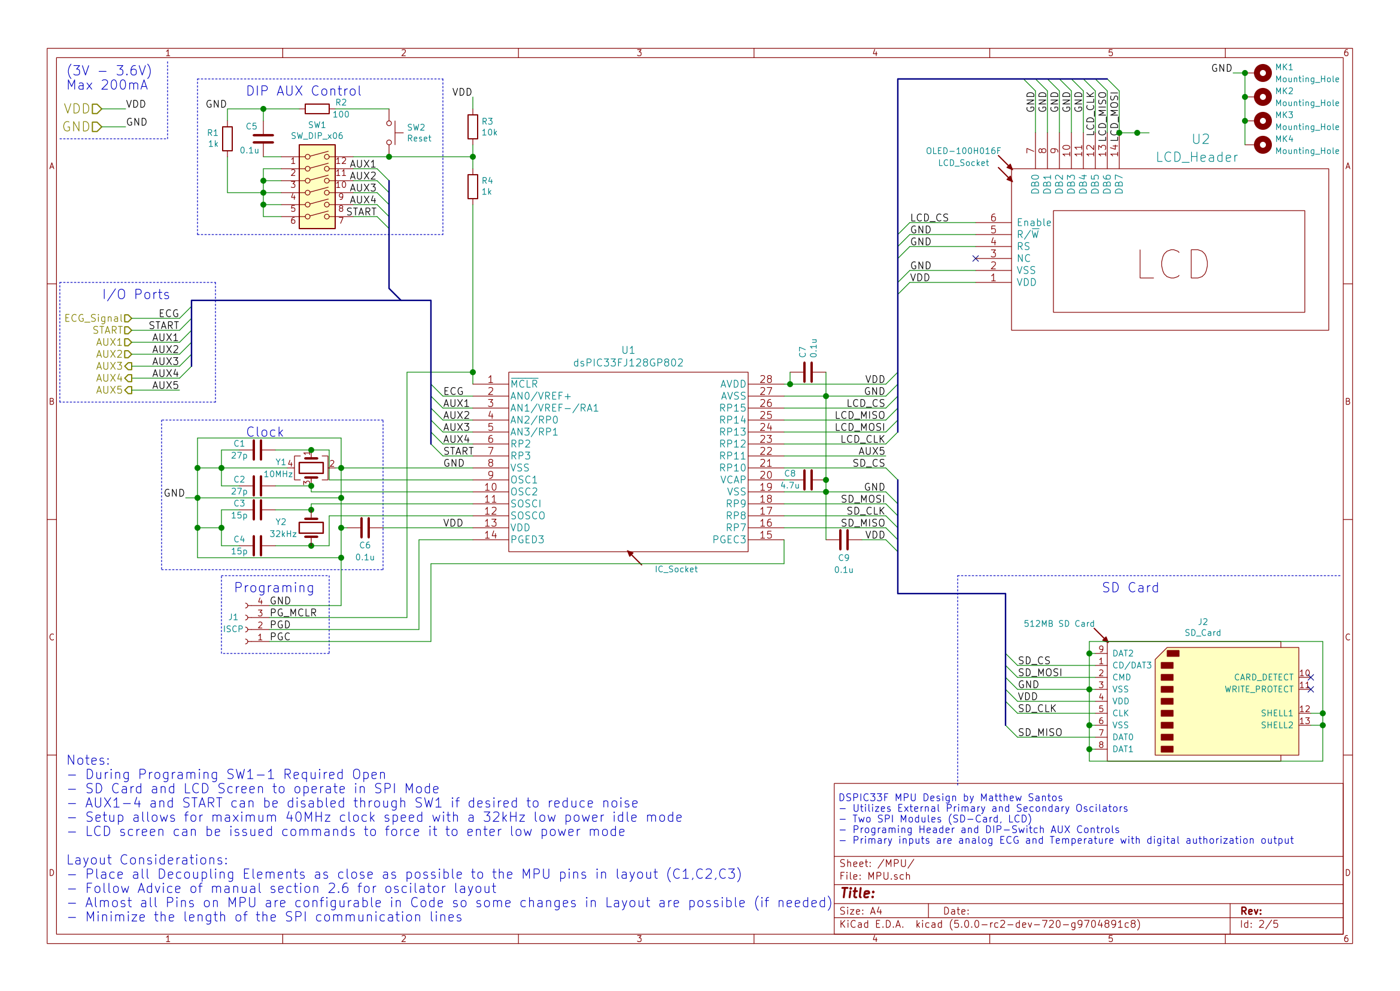
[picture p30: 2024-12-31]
documents/images/Figures/Circuit_Schematic-2.png

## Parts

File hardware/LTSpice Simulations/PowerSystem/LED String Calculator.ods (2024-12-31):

LED Level | Resistance | Ref Voltage | ECG Signal Voltage | Bat Voltage |  | RN9A
Ry | 18000 | 5 | 3 | 6 | Min is ~4.75 | 10000 | Ratio
R1 | 2700 | 3.11 | OFF | OFF |  | RN9B | 0.5
R2 | 2700 | 2.83 | ON | ON |  | 10000
R3 | 2700 | 2.55 | ON | ON
R4 | 2700 | 2.26 | ON | ON
R5 | 2700 | 1.98 | ON | ON
R6 | 2700 | 1.70 | ON | ON
R7 | 2700 | 1.42 | ON | ON
R8 | 2700 | 1.13 | ON | ON
R9 | 2700 | 0.85 | ON | ON
R10 | 2700 | 0.57 | ON | ON
RX | 2700 | 0 | ON | ON
Total Resistance | 47700
Total Current |  | 0.00010
Vin | Vo | Want | R1 | 1
6 | 5.45 | 3 | R2 | 10
5.75 | 5.23 |  | R3 | 10000
5.5 | 5.00 |  | Denom | 110010
5.25 | 4.77 |  | Negative Voltage | 5
5 | 4.54
4.75 | 4.32 | 0
 |  |  | 0.909008271975275 |  | R3 = Total Freedom
 |  |  |  |  | R1 and R3 less than 10k

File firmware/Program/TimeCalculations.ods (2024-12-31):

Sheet: Sheet1
Critical Varribles | Value |  |  | Cycles Needed
Number of People | 50 |  |  | Exponential | Multiplications | Divisions | Additions | Indexing
Number of Features | 27 |  | Integer | 20 | 1 | 18 | 1 | 2
Average SV Size | 600 |  | Floating | 400 | 20 | 360 | 20 | 40
SampleSize | 10000
SampleRate | 500
 |  |  |  | Total Number of Operations to Complete Task
 |  | Tasks | Filter Order | Exponential | Multiplications | Divisions | Additions | Indexing | Cycles/Sec | Cycles Required | Total Time to Complete (from Start)
 |  | ADC | N/A |  |  |  |  | 30000 |  |  | #DIV/0!
 |  | LP Filter | 45 |  | 450000 |  | 450000 | 1350000 |  |  | #DIV/0!
 |  | DC Blocker | 1 |  | 10000 |  | 30000 | 60000 |  |  | #DIV/0!
 |  | Notch |  |  |  |  |  |  |  |  | #DIV/0!
 |  | Wavelet |  |  |  |  |  |  |  |  | #DIV/0!
 |  | Averging |  |  |  |  |  |  |  |  | #DIV/0!
 |  | Wavelet Decomposition |  |  |  |  |  |  |  |  | #DIV/0!
 |  | R-Peak |  |  |  |  |  |  |  |  | #DIV/0!
 |  | Sectioning |  |  |  |  |  |  |  |  | #DIV/0!
 |  | S-Peak |  |  |  |  |  |  |  |  | #DIV/0!
 |  | Q-Peak |  |  |  |  |  |  |  |  | #DIV/0!
 |  | T-Peak |  |  |  |  |  |  |  |  | #DIV/0!
 |  | P-Peak |  |  |  |  |  |  |  |  | #DIV/0!
 |  | Feature Calc |  |  |  |  |  |  |  |  | #DIV/0!
 |  | Feature Norm |  |  |  |  |  |  |  |  | #DIV/0!
 |  | Test Classifiers |  |  | 23490000 |  | 486810000 | 810605 |  |  | #DIV/0!
 |  |  | Cycles | Time
 |  | Integer | 511921210 | 12.79803025 | 23490000 | 0 | 486810000 | 1621210
 |  | Floating | 10238424200 | 255.960605 | 469800000 | 0 | 9736200000 | 32424200

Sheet: Conversions
 | Limits | Analog Voltage [V] | 10bit Signed Fractional | 16bit Signed Fractional | 10bit Signed Integer | 16bit Signed Integer
 | Min (decimal) | 0.00 | -1.000 | -1.00000 | -512 | -32768
 | Max (decimal) | 3.00 | 0.998 | 0.99997 | 511 | 32767
 | Precision (decimal) | Inf | 0.002 | 0.00003 | 1 | 1
Converter | Test Value | Analog | 10bit Fractional | 16bit Fractional | 10bit Integer | 16bit Integer
Analog | 1.8 | 1.800 | 0.200 | 0.20000 | 102 | 102
10bit Fractional | 0.333 | 2.000 | 0.333 | 0.00520 | 170 | 170
16bit Fractional | 0.0052 | 1.999 | 0.333 | 0.00520 | 170 | 170
10bit Integer | 511 | 2.997 | 0.998 | 0.01559 | 511 | 511
16bit Integer | 2294 | 1.605011 | 4.480 | 0.07001 | 2294 | 2294

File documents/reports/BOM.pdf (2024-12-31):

Bill of Materials for Capstone Group #9 | Total # Parts | 116

### Total Cost: $220.50

Part Info | Digi-Key
Ref# Ref Value Manf# Quantity | Part# Available Unit Cost
BAR1 | DC7G3HWA | DC7G3HWA | 1 | 43 | $2.73
BT5 | Battery Holder | BH4AAPC | 1 | 2073 | $5.57
BT1-BT4 | Holder | BK-5091 | 4 | 4220 | $0.42
C1,C2 | 27p | C1206C270F5GACTU | 2 | 3930 | $2.02
C10,C11 | 100p | 885012008004 | 2 | 3319 | $0.15
C12 | 1n | 885012208022 | 1 | 3391 | $0.14
C13,C15,C17 | 0.68u | 885012208012 | 3 | 2715 | $0.46
C14,C16,C19 | 0.068u | 885012208086 | 3 | 2550 | $0.20
C18,C27,C29 | 47u | GRM31CC80J476KE18L | 3 | 20000 | $1.21
C20,C22 | 10u | C3216X5R1C106K160AA | 2 | 6752 | $0.42
C21,C24,C25 | 4.7u | C1206C475K4PACTU | 3 | 20000 | $0.43
C23 | 22u | C1206C226Z9VACTU | 1 | 16816 | $0.57
C26,C28 | 10n | C1206C103J5RACTU | 2 | 30522 | $0.33
C3,C4 | 15p | C1206C150J5GACTU | 2 | 34631 | $0.35
C8 | 4.7u | F931C475KAA | 1 | 221 | $0.56
C5-C7,C9 | 0.1u | C1206C104K4RACTU | 4 | 40000 | $0.20
D1 | SMDA15TR | SMDA15TR | 1 | 2500 | $0.72
D3,D4 | 1N914 | 1N914 | 2 | 23339 | $0.14
F1 | Fuse_Holder | 0031.8201 | 1 | 44234 | $0.95
J1 | ISCP | 61300411121 | 1 | 20525 | $0.25
J2 | SD_Card | 145638009211859+ | 1 | 36044 | $4.22
J3 | EncoderHeader | B4B-XH-A(LF)(SN) | 1 | 184591 | $0.29
J4 | MotorHeader | B2B-XH-A(LF)(SN) | 1 | 147104 | $0.21
L1 | 10u | 77F100K-TR-RC | 1 | 10402 | $0.42
R1,R4 | 1k | RC1206JR-071KL | 2 | 155592 | $0.15
R10,R11,R19 | 2k | RC1206FR-072KL | 3 | 521394 | $0.15
R12 | 82k | RC1206FR-0782KL | 1 | 2699 | $0.15
R13,R14 | 1.5k | CRCW12061K50FKEAC | 2 | 32370 | $0.15
R15 | 9k | RC1206FR-079K09L | 1 | 4463 | $0.15
R17 | 40k | RC1206FR-0740K2L | 1 | 29843 | $0.15
R18 | 15k | AC1206FR-0715KL | 1 | 29346 | $0.15
R2,R16 | 100 | AC1206FR-07100RL | 2 | 21159 | $0.15
R20 | 18k | RC1206FR-0718KL | 1 | 209262 | $0.15
R21 | 2.2k | RC1206JR-072K2L | 1 | 244667 | $0.15
R22 | 3.3k | RC1206FR-073K3L | 1 | 547028 | $0.15
R3 | 10k | RC1206JR-0710KL | 1 | 528040 | $0.15
R5 | 5.6k | RC1206FR-075K6L | 1 | 59375 | $0.15
R6 | 2.4k | RC1206JR-072K4L | 1 | 140621 | $0.15
R7,R8 | 100k | RC1206FR-07100KL | 2 | 1184160 | $0.15
R9 | 3k | RC1206JR-073KL | 1 | 5762 | $0.15
RN1 | 3.3k | 4610X-102-332LF | 1 | 1991 | $0.79
RN10 | 150 | 4606X-102-151LF | 1 | 6101 | $0.62
RN11,RN12 | 2.7k | 770103272P | 2 | 1778 | $1.16
RN13 | 150 | 4610X-101-151LF | 1 | 660 | $0.93
RN2 | 10k | 4608X-102-103LF | 1 | 9321 | $0.85
RN4 | 10k | 4116R-1-103FLF | 1 | 26 | $1.31
RN5 | 1k | 4606X-102-102LF | 1 | 647 | $0.92
RN9 | 10k | 4606X-102-103LF | 1 | 813 | $0.62
RV1 | 5kPOT | PV36W502C01B00 | 1 | 8861 | $2.23
RV2 | 3kPOT | 3362P-1-302LF | 1 | 1245 | $1.51
RV3 | 2kPOT | PV36W202C01B00 | 1 | 2011 | $2.23
RV4 | 100k POT | PV36W104C01B00 | 1 | 14427 | $2.23
RV5 | 500k POT | 3296W-1-504LF | 1 | 4284 | $3.58
SW1 | SW_DIP_x06 | 418117270906 | 1 | 16 | $2.63
SW2 | Reset | TL1105F250Q | 1 | 19655 | $0.25
SW3 | Bat-Test | EG1218 | 1 | 36127 | $0.81
SW4 | Start | UB15SKG035F-FF | 1 | 1787 | $11.65
SYM1 | IC_Socket | ED281DT | 1 | 26059 | $0.46
SYM14 | Motor | FIT0487 | 1 | 170 | $18.19
SYM2 | OLED-100H016F | O100H016FBPP5N0000 | 1 | 12 | $32.83
SYM3 | LCD_Socket | PPTC082LFBN-RC | 1 | 3122 | $1.38
SYM4 | 512MB SD Card | AF512SDI-OEM | 1 | 255 | $20.16
SYM9 | 1A_Fast | 5MF 1-R | 1 | 6689 | $0.29
SYM10-SYM13 | AA | EN91 | 4 | 203877 | $0.19
SYM5-SYM8 | Cell | A76 | 4 | 84722 | $0.79
TH1 | Thermistor | DC103G9G | 1 | 8305 | $1.56

754-1671-5-ND (https://www.digikey.ca/products/en?keywords=DC7G3HWA+)
BH4AA-PC-ND (https://www.digikey.ca/products/en?keywords=BH4AAPC+)
BK-5091-ND (https://www.digikey.ca/products/en?keywords=BK-5091+)
399-9339-1-ND (https://www.digikey.ca/product-detail/en/kemet/C1206C270F5GACTU/399-9339-1-ND/3522857)
732-7864-1-ND (https://www.digikey.ca/product-detail/en/wurth-electronics-inc/885012008004/732-7864-1-ND/5454491)
732-8089-1-ND (https://www.digikey.ca/product-detail/en/wurth-electronics-inc/885012208022/732-8089-1-ND/5454716)
732-7684-1-ND (https://www.digikey.ca/product-detail/en/wurth-electronics-inc/885012208012/732-7684-1-ND/5454311)
732-8126-1-ND (https://www.digikey.ca/product-detail/en/wurth-electronics-inc/885012208086/732-8126-1-ND/5454753)
490-8337-1-ND (https://www.digikey.ca/product-detail/en/murata-electronics-north-america/GRM31CC80J476KE18L/490-8337-1-ND/4380631)
445-4052-1-ND (https://www.digikey.ca/product-detail/en/tdk-corporation/C3216X5R1C106K160AA/445-4052-1-ND/1965698)
399-1265-1-ND (https://www.digikey.ca/product-detail/en/kemet/C1206C475K4PACTU/399-1265-1-ND/411540)
399-3028-1-ND (https://www.digikey.ca/product-detail/en/kemet/C1206C226Z9VACTU/399-3028-1-ND/447583)
399-1237-1-ND (https://www.digikey.ca/product-detail/en/kemet/C1206C103J5RACTU/399-1237-1-ND/411512)
399-1194-1-ND (https://www.digikey.ca/product-detail/en/kemet/C1206C150J5GACTU/399-1194-1-ND/411469)
478-8265-1-ND (https://www.digikey.ca/product-detail/en/avx-corporation/F931C475KAA/478-8265-1-ND/4005701)
399-9305-1-ND (https://www.digikey.ca/product-detail/en/kemet/C1206C104K4RACTU/399-9305-1-ND/3522823)
1655-1914-1-ND (https://www.digikey.ca/product-detail/en/smc-diode-solutions/SMDA15TR/1655-1914-1-ND/8019616)
1N914FS-ND (https://www.digikey.ca/product-detail/en/on-semiconductor/1N914/1N914FS-ND/978749)
486-1258-ND (https://www.digikey.ca/products/en?keywords=0031.8201+)
732-5317-ND (https://www.digikey.ca/products/en?keywords=61300411121+)
478-4059-1-ND (https://www.digikey.ca/product-detail/en/kyocera-international-inc-electronic-components/145638009211859/478-4059-1-ND/869127)
455-2249-ND (https://www.digikey.ca/products/en?keywords=B4B-XH-A%28LF%29%28SN%29+)
455-2247-ND (https://www.digikey.ca/products/en?keywords=B2B-XH-A%28LF%29%28SN%29+)
77F100K-TR-RCCT-ND (https://www.digikey.ca/product-detail/en/bourns-inc/77F100K-TR-RC/77F100K-TR-RCCT-ND/3741658)
311-1.0KERCT-ND (https://www.digikey.ca/product-detail/en/yageo/RC1206JR-071KL/311-1.0KERCT-ND/732133)
311-2.00KFRCT-ND (https://www.digikey.ca/product-detail/en/yageo/RC1206FR-072KL/311-2.00KFRCT-ND/731559)
311-82.0KFRCT-ND (https://www.digikey.ca/product-detail/en/yageo/RC1206FR-0782KL/311-82.0KFRCT-ND/732077)
541-4184-1-ND (https://www.digikey.ca/product-detail/en/vishay-dale/CRCW12061K50FKEAC/541-4184-1-ND/7928867)
311-9.09KFRCT-ND (https://www.digikey.ca/product-detail/en/yageo/RC1206FR-079K09L/311-9.09KFRCT-ND/732097)
311-40.2KFRCT-ND (https://www.digikey.ca/product-detail/en/yageo/RC1206FR-0740K2L/311-40.2KFRCT-ND/731846)
YAG3815CT-ND (https://www.digikey.ca/product-detail/en/yageo/AC1206FR-0715KL/YAG3815CT-ND/6006664)
YAG3804CT-ND (https://www.digikey.ca/product-detail/en/yageo/AC1206FR-07100RL/YAG3804CT-ND/6006653)
311-18.0KFRCT-ND (https://www.digikey.ca/product-detail/en/yageo/RC1206FR-0718KL/311-18.0KFRCT-ND/731539)
311-2.2KERCT-ND (https://www.digikey.ca/product-detail/en/yageo/RC1206JR-072K2L/311-2.2KERCT-ND/732186)
311-3.30KFRCT-ND (https://www.digikey.ca/product-detail/en/yageo/RC1206FR-073K3L/311-3.30KFRCT-ND/731713)
311-10KERCT-ND (https://www.digikey.ca/product-detail/en/yageo/RC1206JR-0710KL/311-10KERCT-ND/732156)
311-5.60KFRCT-ND (https://www.digikey.ca/product-detail/en/yageo/RC1206FR-075K6L/311-5.60KFRCT-ND/731909)
311-2.4KERCT-ND (https://www.digikey.ca/product-detail/en/yageo/RC1206JR-072K4L/311-2.4KERCT-ND/732189)
311-100KFRCT-ND (https://www.digikey.ca/product-detail/en/yageo/RC1206FR-07100KL/311-100KFRCT-ND/731439)
311-3.0KERCT-ND (https://www.digikey.ca/product-detail/en/yageo/RC1206JR-073KL/311-3.0KERCT-ND/732211)
4610X-2-332LF-ND (https://www.digikey.ca/products/en?keywords=4610X-102-332LF+)
4606X-2-151LF-ND (https://www.digikey.ca/products/en?keywords=4606X-102-151LF+)
770-103-R2.7KP-ND (https://www.digikey.ca/products/en?keywords=770103272P+)
4610X-1-151LF-ND (https://www.digikey.ca/products/en?keywords=4610X-101-151LF+)
4608X-2-103LF-ND (https://www.digikey.ca/products/en?keywords=4608X-102-103LF+)
4116R-1-103FLF-ND (https://www.digikey.ca/products/en?keywords=4116R-1-103FLF+)
4606X-2-102LF-ND (https://www.digikey.ca/products/en?keywords=4606X-102-102LF+)
4606X-2-103LF-ND (https://www.digikey.ca/products/en?keywords=4606X-102-103LF+)
490-2888-ND (https://www.digikey.ca/products/en?keywords=PV36W502C01B00+)
3362P-1-302LF-ND (https://www.digikey.ca/products/en?keywords=3362P-1-302LF+)
490-2880-ND (https://www.digikey.ca/products/en?keywords=PV36W202C01B00+)
490-2876-ND (https://www.digikey.ca/products/en?keywords=PV36W104C01B00+)
3296W-504LF-ND (https://www.digikey.ca/products/en?keywords=3296W-1-504LF+)
732-3836-5-ND (https://www.digikey.ca/products/en?keywords=418117270906+)
EG1828-ND (https://www.digikey.ca/products/en?keywords=TL1105F250Q+)
EG1903-ND (https://www.digikey.ca/product-detail/en/e-switch/EG1218/EG1903-ND/101726)
360-1947-ND (https://www.digikey.ca/products/en?keywords=UB15SKG035F-FF+)
ED3050-5-ND (https://www.digikey.ca/products/en?keywords=ED281DT+)
1738-1267-ND (https://www.digikey.ca/products/en?keywords=FIT0487+)
541-3451-ND (https://www.digikey.ca/products/en?keywords=O100H016FBPP5N0000+)
S7076-ND (https://www.digikey.ca/products/en?keywords=PPTC082LFBN-RC+)
AF512SDI-OEM-ND (https://www.digikey.ca/products/en?keywords=AF512SDI-OEM+)
507-1261-ND (https://www.digikey.ca/product-detail/en/bel-fuse-inc/5MF-1-R/507-1261-ND/1009033)
N107-ND (https://www.digikey.ca/product-detail/en/energizer-battery-company/EN91/N107-ND/704822)
N402-ND (https://www.digikey.ca/product-detail/en/energizer-battery-company/A76/N402-ND/704827)
615-1054-ND (https://www.digikey.ca/products/en?keywords=DC103G9G+)

U1 | dsPIC33FJ128GP802 DSPIC33FJ128GP802-I/SP | 1 | 133 | $8.13
U12 | P7805-Q24-S3-S | P7805-Q24-S3-S | 1 | 1506 | $6.88
U13 | PDM1-S5-D5-S | PDM1-S5-D5-S | 1 | 546 | $6.27
U14,U17 | LM339 | LM339N | 2 | 263889 | $0.74
U15 | NE556 | NE556N | 1 | 4835 | $0.79
U18 | 74HC74 | SN74HCT74N | 1 | 1711 | $0.70
U2 | LCD_Header | 67996-416HLF | 1 | 3007 | $0.84
U20 | L293DNE | L293DNE | 1 | 5205 | $5.13
U21 | LM2903 | LM2903P | 1 | 10827 | $0.61
U5 | LT1079CN | LT1079CN#PBF | 1 | 1008 | $10.34
U6,U11 | TLC2264IN | TLC2264IN | 2 | 3348 | $3.46
U8 | LT1636 | LT1636CN8#PBF | 1 | 395 | $4.38
U9 | IL300 | IL300-F | 1 | 8575 | $16.01
Y1 | 10MHz | ABMM-10.000MHZ-B2-T | 1 | 4228 | $1.37
Y2 | 32kHz | AB38T-32.768KHZ | 1 | 37808 | $0.25

DSPIC33FJ128GP802-I/SP-ND (https://www.digikey.ca/products/en?keywords=DSPIC33FJ128GP802-I%2FSP+)
102-2704-ND (https://www.digikey.ca/products/en?keywords=P7805-Q24-S3-S+)
102-2722-ND (https://www.digikey.ca/products/en?keywords=PDM1-S5-D5-S+)
296-1393-5-ND (https://www.digikey.ca/product-detail/en/texas-instruments/LM339N/296-1393-5-ND/277628)
296-6504-5-ND (https://www.digikey.ca/product-detail/en/texas-instruments/NE556N/296-6504-5-ND/372495)
296-1625-5-ND (https://www.digikey.ca/product-detail/en/texas-instruments/SN74HCT74N/296-1625-5-ND/277271)
609-3220-ND (https://www.digikey.ca/products/en?keywords=67996-416HLF+)
296-9518-5-ND (https://www.digikey.ca/product-detail/en/texas-instruments/L293DNE/296-9518-5-ND/379724)
296-6601-5-ND (https://www.digikey.ca/product-detail/en/texas-instruments/LM2903P/296-6601-5-ND/372786)
LT1079CN#PBF-ND (https://www.digikey.ca/products/en?keywords=LT1079CN%23PBF+)
296-7107-5-ND (https://www.digikey.ca/products/en?keywords=296-7107-5-ND)
LT1636CN8#PBF-ND (https://www.digikey.ca/products/en?keywords=LT1636CN8%23PBF-ND)
751-1296-5-ND (https://www.digikey.ca/product-detail/en/vishay-semiconductor-opto-division/IL300-F/751-1296-5-ND/1731529)
535-9150-1-ND (https://www.digikey.ca/product-detail/en/abracon-llc/ABMM-10.000MHZ-B2-T/535-9150-1-ND/675667)
535-9034-ND (https://www.digikey.ca/product-detail/en/abracon-llc/AB38T-32.768KHZ/535-9034-ND/675229)

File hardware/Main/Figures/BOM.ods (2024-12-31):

 | Bill of Materials for Capstone Group #9 |  |  | Total # Parts | 116
 |  |  |  | Total Cost: | $220.50
Part Info |  |  |  | Digi-Key |  |  | Digi-Key BOM List
Ref# | Ref Value | Manf# | Quantity | Part# | Available | Unit Cost | Part# | Quantity
BAR1 | DC7G3HWA | DC7G3HWA | 1 | 754-1671-5-ND (https://www.digikey.ca/products/en?keywords=DC7G3HWA+) | 43 | $2.73 | 754-1671-5-ND | 1
BT5 | Battery Holder | BH4AAPC | 1 | BH4AA-PC-ND (https://www.digikey.ca/products/en?keywords=BH4AAPC+) | 2073 | $5.57 | BH4AA-PC-ND | 1
BT1-BT4 | Holder | BK-5091 | 4 | BK-5091-ND (https://www.digikey.ca/products/en?keywords=BK-5091+) | 4220 | $0.42 | BK-5091-ND | 4
C1,C2 | 27p | C1206C270F5GACTU | 2 | 399-9339-1-ND (https://www.digikey.ca/product-detail/en/kemet/C1206C270F5GACTU/399-9339-1-ND/3522857) | 3930 | $2.02 | 399-9339-1-ND | 2
C10,C11 | 100p | 885012008004 | 2 | 732-7864-1-ND (https://www.digikey.ca/product-detail/en/wurth-electronics-inc/885012008004/732-7864-1-ND/5454491) | 3319 | $0.15 | 732-7864-1-ND | 2
C12 | 1n | 885012208022 | 1 | 732-8089-1-ND (https://www.digikey.ca/product-detail/en/wurth-electronics-inc/885012208022/732-8089-1-ND/5454716) | 3391 | $0.14 | 732-8089-1-ND | 1
C13,C15,C17 | 0.68u | 885012208012 | 3 | 732-7684-1-ND (https://www.digikey.ca/product-detail/en/wurth-electronics-inc/885012208012/732-7684-1-ND/5454311) | 2715 | $0.46 | 732-7684-1-ND | 3
C14,C16,C19 | 0.068u | 885012208086 | 3 | 732-8126-1-ND (https://www.digikey.ca/product-detail/en/wurth-electronics-inc/885012208086/732-8126-1-ND/5454753) | 2550 | $0.20 | 732-8126-1-ND | 3
C18,C27,C29 | 47u | GRM31CC80J476KE18L | 3 | 490-8337-1-ND (https://www.digikey.ca/product-detail/en/murata-electronics-north-america/GRM31CC80J476KE18L/490-8337-1-ND/4380631) | 20000 | $1.21 | 490-8337-1-ND | 3
C20,C22 | 10u | C3216X5R1C106K160AA | 2 | 445-4052-1-ND (https://www.digikey.ca/product-detail/en/tdk-corporation/C3216X5R1C106K160AA/445-4052-1-ND/1965698) | 6752 | $0.42 | 445-4052-1-ND | 2
C21,C24,C25 | 4.7u | C1206C475K4PACTU | 3 | 399-1265-1-ND (https://www.digikey.ca/product-detail/en/kemet/C1206C475K4PACTU/399-1265-1-ND/411540) | 20000 | $0.43 | 399-1265-1-ND | 3
C23 | 22u | C1206C226Z9VACTU | 1 | 399-3028-1-ND (https://www.digikey.ca/product-detail/en/kemet/C1206C226Z9VACTU/399-3028-1-ND/447583) | 16816 | $0.57 | 399-3028-1-ND | 1
C26,C28 | 10n | C1206C103J5RACTU | 2 | 399-1237-1-ND (https://www.digikey.ca/product-detail/en/kemet/C1206C103J5RACTU/399-1237-1-ND/411512) | 30522 | $0.33 | 399-1237-1-ND | 2
C3,C4 | 15p | C1206C150J5GACTU | 2 | 399-1194-1-ND (https://www.digikey.ca/product-detail/en/kemet/C1206C150J5GACTU/399-1194-1-ND/411469) | 34631 | $0.35 | 399-1194-1-ND | 2
C8 | 4.7u | F931C475KAA | 1 | 478-8265-1-ND (https://www.digikey.ca/product-detail/en/avx-corporation/F931C475KAA/478-8265-1-ND/4005701) | 221 | $0.56 | 478-8265-1-ND | 1
C5-C7,C9 | 0.1u | C1206C104K4RACTU | 4 | 399-9305-1-ND (https://www.digikey.ca/product-detail/en/kemet/C1206C104K4RACTU/399-9305-1-ND/3522823) | 40000 | $0.20 | 399-9305-1-ND | 4
D1 | SMDA15TR | SMDA15TR | 1 | 1655-1914-1-ND (https://www.digikey.ca/product-detail/en/smc-diode-solutions/SMDA15TR/1655-1914-1-ND/8019616) | 2500 | $0.72 | 1655-1914-1-ND | 1
D3,D4 | 1N914 | 1N914 | 2 | 1N914FS-ND (https://www.digikey.ca/product-detail/en/on-semiconductor/1N914/1N914FS-ND/978749) | 23339 | $0.14 | 1N914FS-ND | 2
F1 | Fuse_Holder | 0031.8201 | 1 | 486-1258-ND (https://www.digikey.ca/products/en?keywords=0031.8201+) | 44234 | $0.95 | 486-1258-ND | 1
J1 | ISCP | 61300411121 | 1 | 732-5317-ND (https://www.digikey.ca/products/en?keywords=61300411121+) | 20525 | $0.25 | 732-5317-ND | 1
J2 | SD_Card | 145638009211859+ | 1 | 478-4059-1-ND (https://www.digikey.ca/product-detail/en/kyocera-international-inc-electronic-components/145638009211859/478-4059-1-ND/869127) | 36044 | $4.22 | 478-4059-1-ND | 1
J3 | EncoderHeader | B4B-XH-A(LF)(SN) | 1 | 455-2249-ND (https://www.digikey.ca/products/en?keywords=B4B-XH-A%28LF%29%28SN%29+) | 184591 | $0.29 | 455-2249-ND | 1
J4 | MotorHeader | B2B-XH-A(LF)(SN) | 1 | 455-2247-ND (https://www.digikey.ca/products/en?keywords=B2B-XH-A%28LF%29%28SN%29+) | 147104 | $0.21 | 455-2247-ND | 1
L1 | 10u | 77F100K-TR-RC | 1 | 77F100K-TR-RCCT-ND (https://www.digikey.ca/product-detail/en/bourns-inc/77F100K-TR-RC/77F100K-TR-RCCT-ND/3741658) | 10402 | $0.42 | 77F100K-TR-RCCT-ND | 1
R1,R4 | 1k | RC1206JR-071KL | 2 | 311-1.0KERCT-ND (https://www.digikey.ca/product-detail/en/yageo/RC1206JR-071KL/311-1.0KERCT-ND/732133) | 155592 | $0.15 | 311-1.0KERCT-ND | 2
R10,R11,R19 | 2k | RC1206FR-072KL | 3 | 311-2.00KFRCT-ND (https://www.digikey.ca/product-detail/en/yageo/RC1206FR-072KL/311-2.00KFRCT-ND/731559) | 521394 | $0.15 | 311-2.00KFRCT-ND | 3
R12 | 82k | RC1206FR-0782KL | 1 | 311-82.0KFRCT-ND (https://www.digikey.ca/product-detail/en/yageo/RC1206FR-0782KL/311-82.0KFRCT-ND/732077) | 2699 | $0.15 | 311-82.0KFRCT-ND | 1
R13,R14 | 1.5k | CRCW12061K50FKEAC | 2 | 541-4184-1-ND (https://www.digikey.ca/product-detail/en/vishay-dale/CRCW12061K50FKEAC/541-4184-1-ND/7928867) | 32370 | $0.15 | 541-4184-1-ND | 2
R15 | 9k | RC1206FR-079K09L | 1 | 311-9.09KFRCT-ND (https://www.digikey.ca/product-detail/en/yageo/RC1206FR-079K09L/311-9.09KFRCT-ND/732097) | 4463 | $0.15 | 311-9.09KFRCT-ND | 1
R17 | 40k | RC1206FR-0740K2L | 1 | 311-40.2KFRCT-ND (https://www.digikey.ca/product-detail/en/yageo/RC1206FR-0740K2L/311-40.2KFRCT-ND/731846) | 29843 | $0.15 | 311-40.2KFRCT-ND | 1
R18 | 15k | AC1206FR-0715KL | 1 | YAG3815CT-ND (https://www.digikey.ca/product-detail/en/yageo/AC1206FR-0715KL/YAG3815CT-ND/6006664) | 29346 | $0.15 | YAG3815CT-ND | 1
R2,R16 | 100 | AC1206FR-07100RL | 2 | YAG3804CT-ND (https://www.digikey.ca/product-detail/en/yageo/AC1206FR-07100RL/YAG3804CT-ND/6006653) | 21159 | $0.15 | YAG3804CT-ND | 2
R20 | 18k | RC1206FR-0718KL | 1 | 311-18.0KFRCT-ND (https://www.digikey.ca/product-detail/en/yageo/RC1206FR-0718KL/311-18.0KFRCT-ND/731539) | 209262 | $0.15 | 311-18.0KFRCT-ND | 1
R21 | 2.2k | RC1206JR-072K2L | 1 | 311-2.2KERCT-ND (https://www.digikey.ca/product-detail/en/yageo/RC1206JR-072K2L/311-2.2KERCT-ND/732186) | 244667 | $0.15 | 311-2.2KERCT-ND | 1
R22 | 3.3k | RC1206FR-073K3L | 1 | 311-3.30KFRCT-ND (https://www.digikey.ca/product-detail/en/yageo/RC1206FR-073K3L/311-3.30KFRCT-ND/731713) | 547028 | $0.15 | 311-3.30KFRCT-ND | 1
R3 | 10k | RC1206JR-0710KL | 1 | 311-10KERCT-ND (https://www.digikey.ca/product-detail/en/yageo/RC1206JR-0710KL/311-10KERCT-ND/732156) | 528040 | $0.15 | 311-10KERCT-ND | 1
R5 | 5.6k | RC1206FR-075K6L | 1 | 311-5.60KFRCT-ND (https://www.digikey.ca/product-detail/en/yageo/RC1206FR-075K6L/311-5.60KFRCT-ND/731909) | 59375 | $0.15 | 311-5.60KFRCT-ND | 1
R6 | 2.4k | RC1206JR-072K4L | 1 | 311-2.4KERCT-ND (https://www.digikey.ca/product-detail/en/yageo/RC1206JR-072K4L/311-2.4KERCT-ND/732189) | 140621 | $0.15 | 311-2.4KERCT-ND | 1
R7,R8 | 100k | RC1206FR-07100KL | 2 | 311-100KFRCT-ND (https://www.digikey.ca/product-detail/en/yageo/RC1206FR-07100KL/311-100KFRCT-ND/731439) | 1184160 | $0.15 | 311-100KFRCT-ND | 2
R9 | 3k | RC1206JR-073KL | 1 | 311-3.0KERCT-ND (https://www.digikey.ca/product-detail/en/yageo/RC1206JR-073KL/311-3.0KERCT-ND/732211) | 5762 | $0.15 | 311-3.0KERCT-ND | 1
RN1 | 3.3k | 4610X-102-332LF | 1 | 4610X-2-332LF-ND (https://www.digikey.ca/products/en?keywords=4610X-102-332LF+) | 1991 | $0.79 | 4610X-2-332LF-ND | 1
RN10 | 150 | 4606X-102-151LF | 1 | 4606X-2-151LF-ND (https://www.digikey.ca/products/en?keywords=4606X-102-151LF+) | 6101 | $0.62 | 4606X-2-151LF-ND | 1
RN11,RN12 | 2.7k | 770103272P | 2 | 770-103-R2.7KP-ND (https://www.digikey.ca/products/en?keywords=770103272P+) | 1778 | $1.16 | 770-103-R2.7KP-ND | 2
RN13 | 150 | 4610X-101-151LF | 1 | 4610X-1-151LF-ND (https://www.digikey.ca/products/en?keywords=4610X-101-151LF+) | 660 | $0.93 | 4610X-1-151LF-ND | 1
RN2 | 10k | 4608X-102-103LF | 1 | 4608X-2-103LF-ND (https://www.digikey.ca/products/en?keywords=4608X-102-103LF+) | 9321 | $0.85 | 4608X-2-103LF-ND | 1
RN4 | 10k | 4116R-1-103FLF | 1 | 4116R-1-103FLF-ND (https://www.digikey.ca/products/en?keywords=4116R-1-103FLF+) | 26 | $1.31 | 4116R-1-103FLF-ND | 1
RN5 | 1k | 4606X-102-102LF | 1 | 4606X-2-102LF-ND (https://www.digikey.ca/products/en?keywords=4606X-102-102LF+) | 647 | $0.92 | 4606X-2-102LF-ND | 1
RN9 | 10k | 4606X-102-103LF | 1 | 4606X-2-103LF-ND (https://www.digikey.ca/products/en?keywords=4606X-102-103LF+) | 813 | $0.62 | 4606X-2-103LF-ND | 1
RV1 | 5kPOT | PV36W502C01B00 | 1 | 490-2888-ND (https://www.digikey.ca/products/en?keywords=PV36W502C01B00+) | 8861 | $2.23 | 490-2888-ND | 1
RV2 | 3kPOT | 3362P-1-302LF | 1 | 3362P-1-302LF-ND (https://www.digikey.ca/products/en?keywords=3362P-1-302LF+) | 1245 | $1.51 | 3362P-1-302LF-ND | 1
RV3 | 2kPOT | PV36W202C01B00 | 1 | 490-2880-ND (https://www.digikey.ca/products/en?keywords=PV36W202C01B00+) | 2011 | $2.23 | 490-2880-ND | 1
RV4 | 100k POT | PV36W104C01B00 | 1 | 490-2876-ND (https://www.digikey.ca/products/en?keywords=PV36W104C01B00+) | 14427 | $2.23 | 490-2876-ND | 1
RV5 | 500k POT | 3296W-1-504LF | 1 | 3296W-504LF-ND (https://www.digikey.ca/products/en?keywords=3296W-1-504LF+) | 4284 | $3.58 | 3296W-504LF-ND | 1
SW1 | SW_DIP_x06 | 418117270906 | 1 | 732-3836-5-ND (https://www.digikey.ca/products/en?keywords=418117270906+) | 16 | $2.63 | 732-3836-5-ND | 1
SW2 | Reset | TL1105F250Q | 1 | EG1828-ND (https://www.digikey.ca/products/en?keywords=TL1105F250Q+) | 19655 | $0.25 | EG1828-ND | 1
SW3 | Bat-Test | EG1218 | 1 | EG1903-ND (https://www.digikey.ca/product-detail/en/e-switch/EG1218/EG1903-ND/101726) | 36127 | $0.81 | EG1903-ND | 1
SW4 | Start | UB15SKG035F-FF | 1 | 360-1947-ND (https://www.digikey.ca/products/en?keywords=UB15SKG035F-FF+) | 1787 | $11.65 | 360-1947-ND | 1
SYM1 | IC_Socket | ED281DT | 1 | ED3050-5-ND (https://www.digikey.ca/products/en?keywords=ED281DT+) | 26059 | $0.46 | ED3050-5-ND | 1
SYM14 | Motor | FIT0487 | 1 | 1738-1267-ND (https://www.digikey.ca/products/en?keywords=FIT0487+) | 170 | $18.19 | 1738-1267-ND | 1
SYM2 | OLED-100H016F | O100H016FBPP5N0000 | 1 | 541-3451-ND (https://www.digikey.ca/products/en?keywords=O100H016FBPP5N0000+) | 12 | $32.83 | 541-3451-ND | 1
SYM3 | LCD_Socket | PPTC082LFBN-RC | 1 | S7076-ND (https://www.digikey.ca/products/en?keywords=PPTC082LFBN-RC+) | 3122 | $1.38 | S7076-ND | 1
SYM4 | 512MB SD Card | AF512SDI-OEM | 1 | AF512SDI-OEM-ND (https://www.digikey.ca/products/en?keywords=AF512SDI-OEM+) | 255 | $20.16 | AF512SDI-OEM-ND | 1
SYM9 | 1A_Fast | 5MF 1-R | 1 | 507-1261-ND (https://www.digikey.ca/product-detail/en/bel-fuse-inc/5MF-1-R/507-1261-ND/1009033) | 6689 | $0.29 | 507-1261-ND | 1
SYM10-SYM13 | AA | EN91 | 4 | N107-ND (https://www.digikey.ca/product-detail/en/energizer-battery-company/EN91/N107-ND/704822) | 203877 | $0.19 | N107-ND | 4
SYM5-SYM8 | Cell | A76 | 4 | N402-ND (https://www.digikey.ca/product-detail/en/energizer-battery-company/A76/N402-ND/704827) | 84722 | $0.79 | N402-ND | 4
TH1 | Thermistor | DC103G9G | 1 | 615-1054-ND (https://www.digikey.ca/products/en?keywords=DC103G9G+) | 8305 | $1.56 | 615-1054-ND | 1
U1 | dsPIC33FJ128GP802 | DSPIC33FJ128GP802-I/SP | 1 | DSPIC33FJ128GP802-I/SP-ND (https://www.digikey.ca/products/en?keywords=DSPIC33FJ128GP802-I%2FSP+) | 133 | $8.13 | DSPIC33FJ128GP802-I/SP-ND | 1
U12 | P7805-Q24-S3-S | P7805-Q24-S3-S | 1 | 102-2704-ND (https://www.digikey.ca/products/en?keywords=P7805-Q24-S3-S+) | 1506 | $6.88 | 102-2704-ND | 1
U13 | PDM1-S5-D5-S | PDM1-S5-D5-S | 1 | 102-2722-ND (https://www.digikey.ca/products/en?keywords=PDM1-S5-D5-S+) | 546 | $6.27 | 102-2722-ND | 1
U14,U17 | LM339 | LM339N | 2 | 296-1393-5-ND (https://www.digikey.ca/product-detail/en/texas-instruments/LM339N/296-1393-5-ND/277628) | 263889 | $0.74 | 296-1393-5-ND | 2
U15 | NE556 | NE556N | 1 | 296-6504-5-ND (https://www.digikey.ca/product-detail/en/texas-instruments/NE556N/296-6504-5-ND/372495) | 4835 | $0.79 | 296-6504-5-ND | 1
U18 | 74HC74 | SN74HCT74N | 1 | 296-1625-5-ND (https://www.digikey.ca/product-detail/en/texas-instruments/SN74HCT74N/296-1625-5-ND/277271) | 1711 | $0.70 | 296-1625-5-ND | 1
U2 | LCD_Header | 67996-416HLF | 1 | 609-3220-ND (https://www.digikey.ca/products/en?keywords=67996-416HLF+) | 3007 | $0.84 | 609-3220-ND | 1
U20 | L293DNE | L293DNE | 1 | 296-9518-5-ND (https://www.digikey.ca/product-detail/en/texas-instruments/L293DNE/296-9518-5-ND/379724) | 5205 | $5.13 | 296-9518-5-ND | 1
U21 | LM2903 | LM2903P | 1 | 296-6601-5-ND (https://www.digikey.ca/product-detail/en/texas-instruments/LM2903P/296-6601-5-ND/372786) | 10827 | $0.61 | 296-6601-5-ND | 1
U5 | LT1079CN | LT1079CN#PBF | 1 | LT1079CN#PBF-ND (https://www.digikey.ca/products/en?keywords=LT1079CN%23PBF+) | 1008 | $10.34 | LT1079CN#PBF-ND | 1
U6,U11 | TLC2264IN | TLC2264IN | 2 | 296-7107-5-ND (https://www.digikey.ca/products/en?keywords=296-7107-5-ND) | 3348 | $3.46 | 296-7107-5-ND | 2
U8 | LT1636 | LT1636CN8#PBF | 1 | LT1636CN8#PBF-ND (https://www.digikey.ca/products/en?keywords=LT1636CN8%23PBF-ND) | 395 | $4.38 | LT1636CN8#PBF-ND | 1
U9 | IL300 | IL300-F | 1 | 751-1296-5-ND (https://www.digikey.ca/product-detail/en/vishay-semiconductor-opto-division/IL300-F/751-1296-5-ND/1731529) | 8575 | $16.01 | 751-1296-5-ND | 1
Y1 | 10MHz | ABMM-10.000MHZ-B2-T | 1 | 535-9150-1-ND (https://www.digikey.ca/product-detail/en/abracon-llc/ABMM-10.000MHZ-B2-T/535-9150-1-ND/675667) | 4228 | $1.37 | 535-9150-1-ND | 1
Y2 | 32kHz | AB38T-32.768KHZ | 1 | 535-9034-ND (https://www.digikey.ca/product-detail/en/abracon-llc/AB38T-32.768KHZ/535-9034-ND/675229) | 37808 | $0.25 | 535-9034-ND | 1

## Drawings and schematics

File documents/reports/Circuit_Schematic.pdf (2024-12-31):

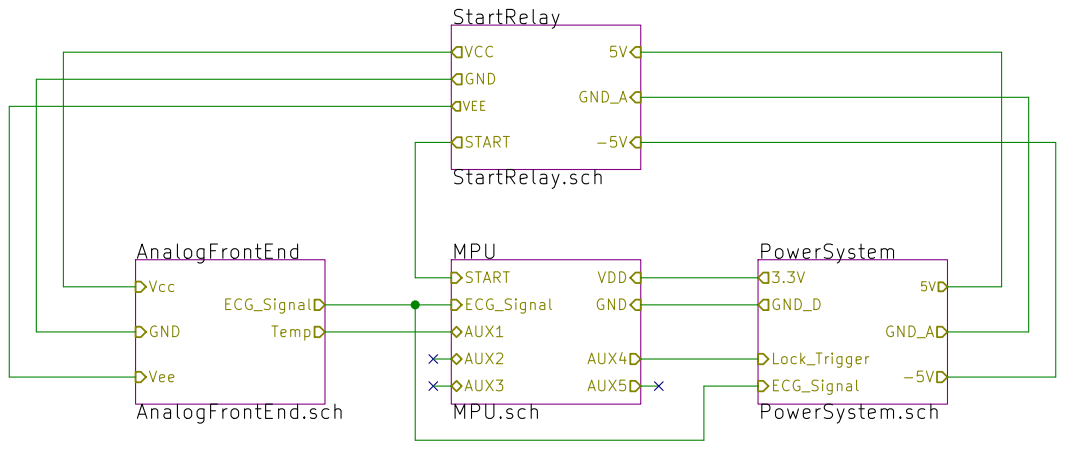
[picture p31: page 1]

Id: 1/5 Title: File: Main.sch Sheet: / MPU

Cardless Security System Block Level Connections Design by Capstone Group #9
- Analog Front End handles analog sensor measurement
- MPU performs analysis and drives the peripherals
- Power System supplies regulated voltages and actuates the door lock
- Power Relay handles system start button activation

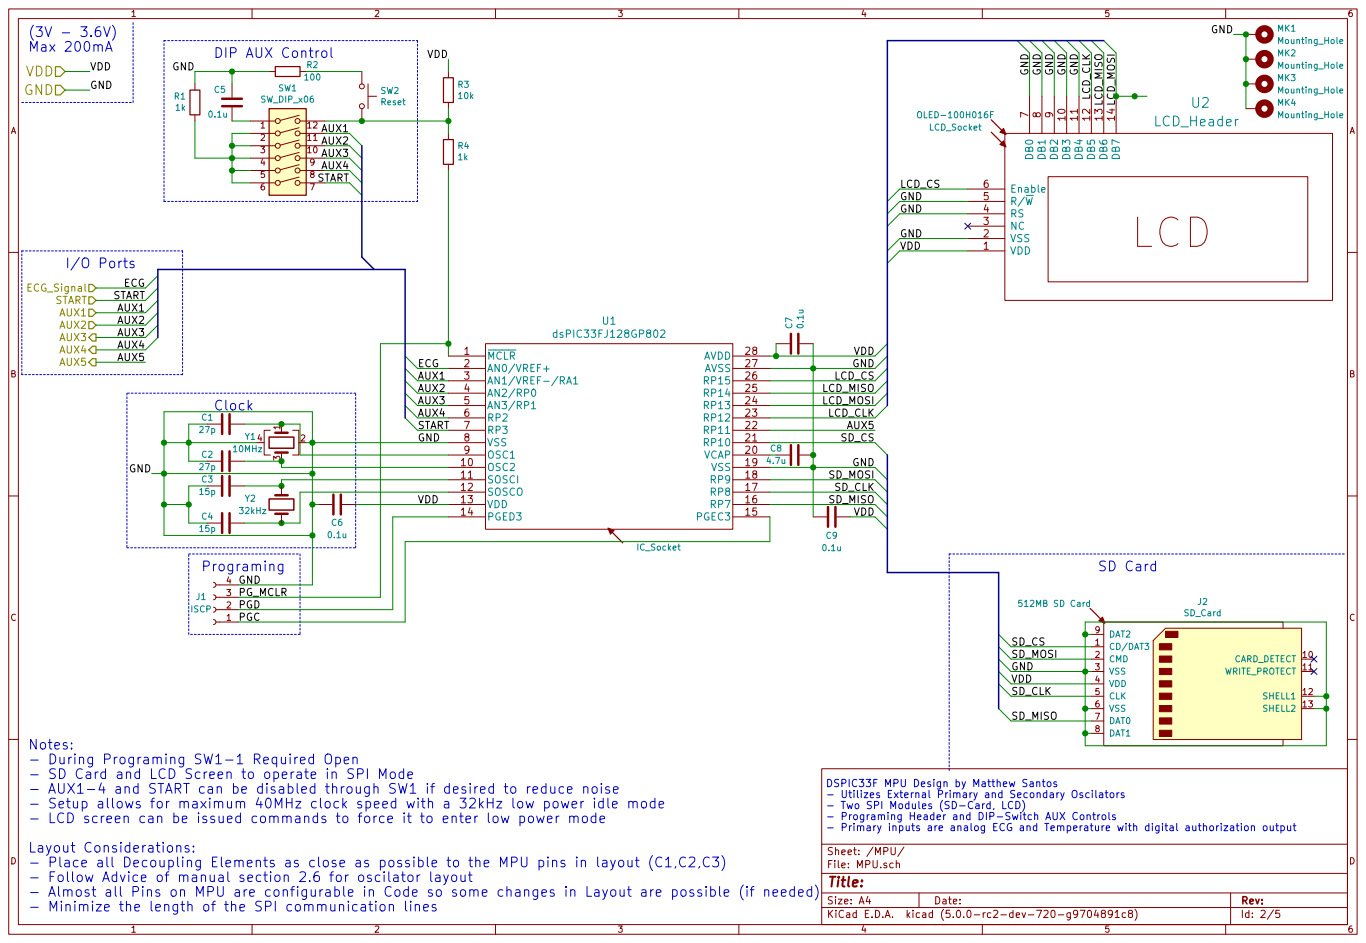
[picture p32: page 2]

START AUX1 AUX2 START AUX1 AUX2 START ECG

2 | 11
3 | 10

LCD_MISO
LCD_MOSI

VDD GND

SD_MOSI
SD_CLK

C6 | SD_MISO

Notes:
- During Programing SW1-1 Required Open
- SD Card and LCD Screen to operate in SPI Mode
- AUX1-4 and START can be disabled through SW1 if desired to reduce noise
- Setup allows for maximum 40MHz clock speed with a 32kHz low power idle mode
- LCD screen can be issued commands to force it to enter low power mode
Layout Considerations:
- Place all Decoupling Elements as close as possible to the MPU pins in layout (C1,C2,C3)
- Follow Advice of manual section 2.6 for oscilator layout
- Almost all Pins on MPU are configurable in Code so some changes in Layout are possible (if needed)
- Minimize the length of the SPI communication lines

- Utilizes External Primary and Secondary Oscilators
- Two SPI Modules (SD-Card, LCD)
- Programing Header and DIP-Switch AUX Controls
- Primary inputs are analog ECG and Temperature with digital authorization output

Id: 2/5 Title: File: MPU.sch Sheet: /MPU/

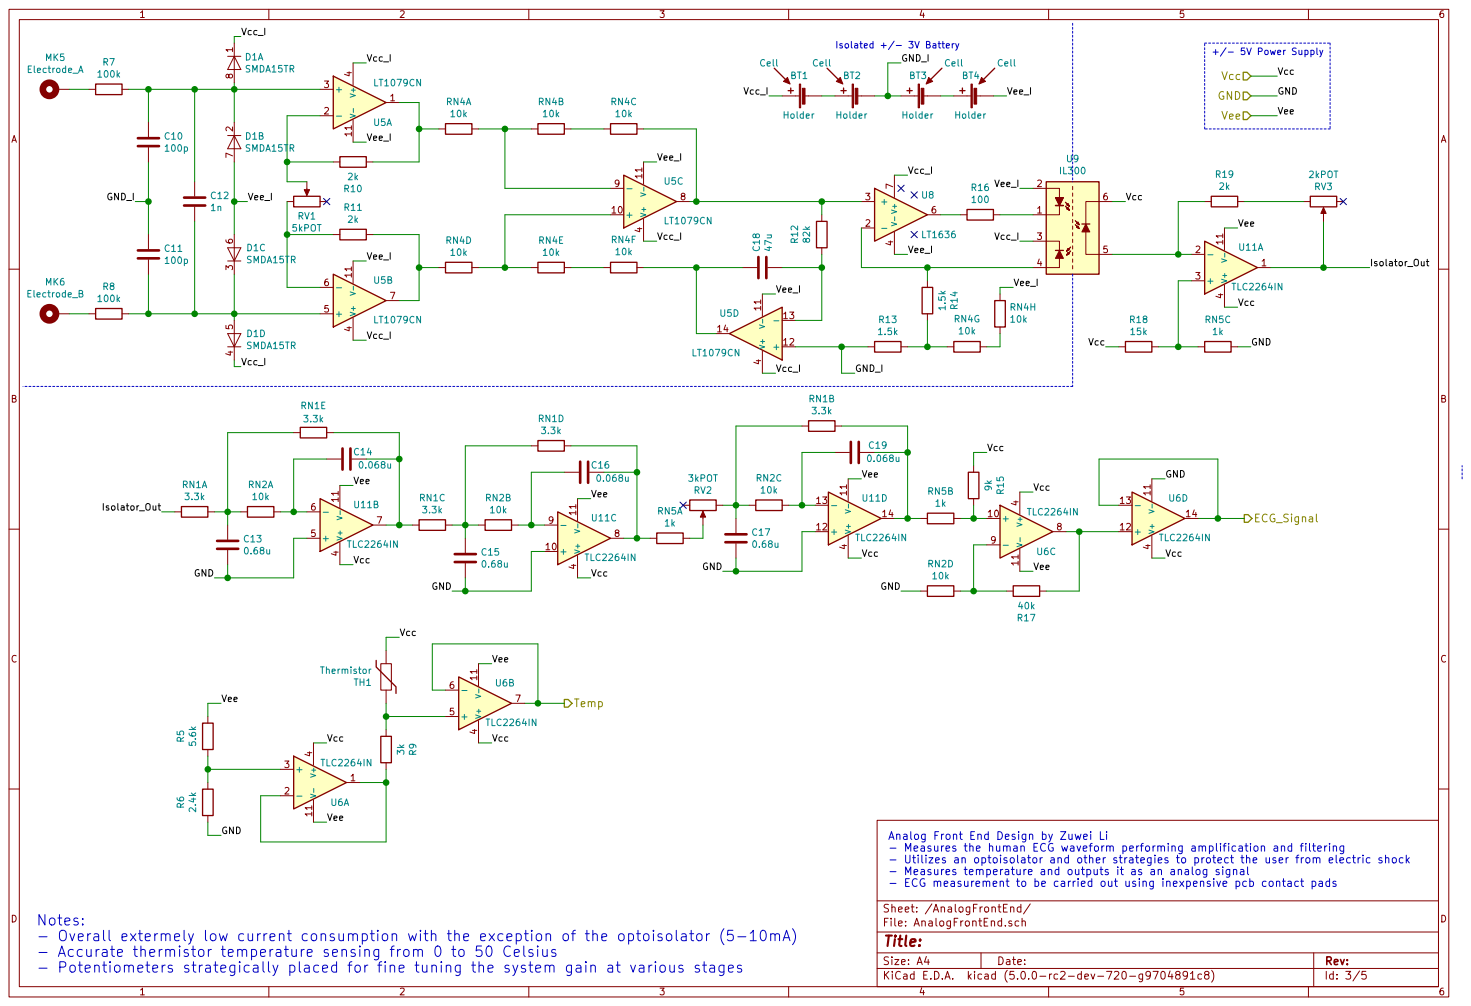
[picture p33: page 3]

Analog Front End Design by Zuwei Li
- Measures the human ECG waveform performing amplification and filtering
- Utilizes an optoisolator and other strategies to protect the user from electric shock
- Measures temperature and outputs it as an analog signal
- ECG measurement to be carried out using inexpensive pcb contact pads

- Overall extermely low current consumption with the exception of the optoisolator (5-10mA)
- Accurate thermistor temperature sensing from 0 to 50 Celsius
- Potentiometers strategically placed for fine tuning the system gain at various stages

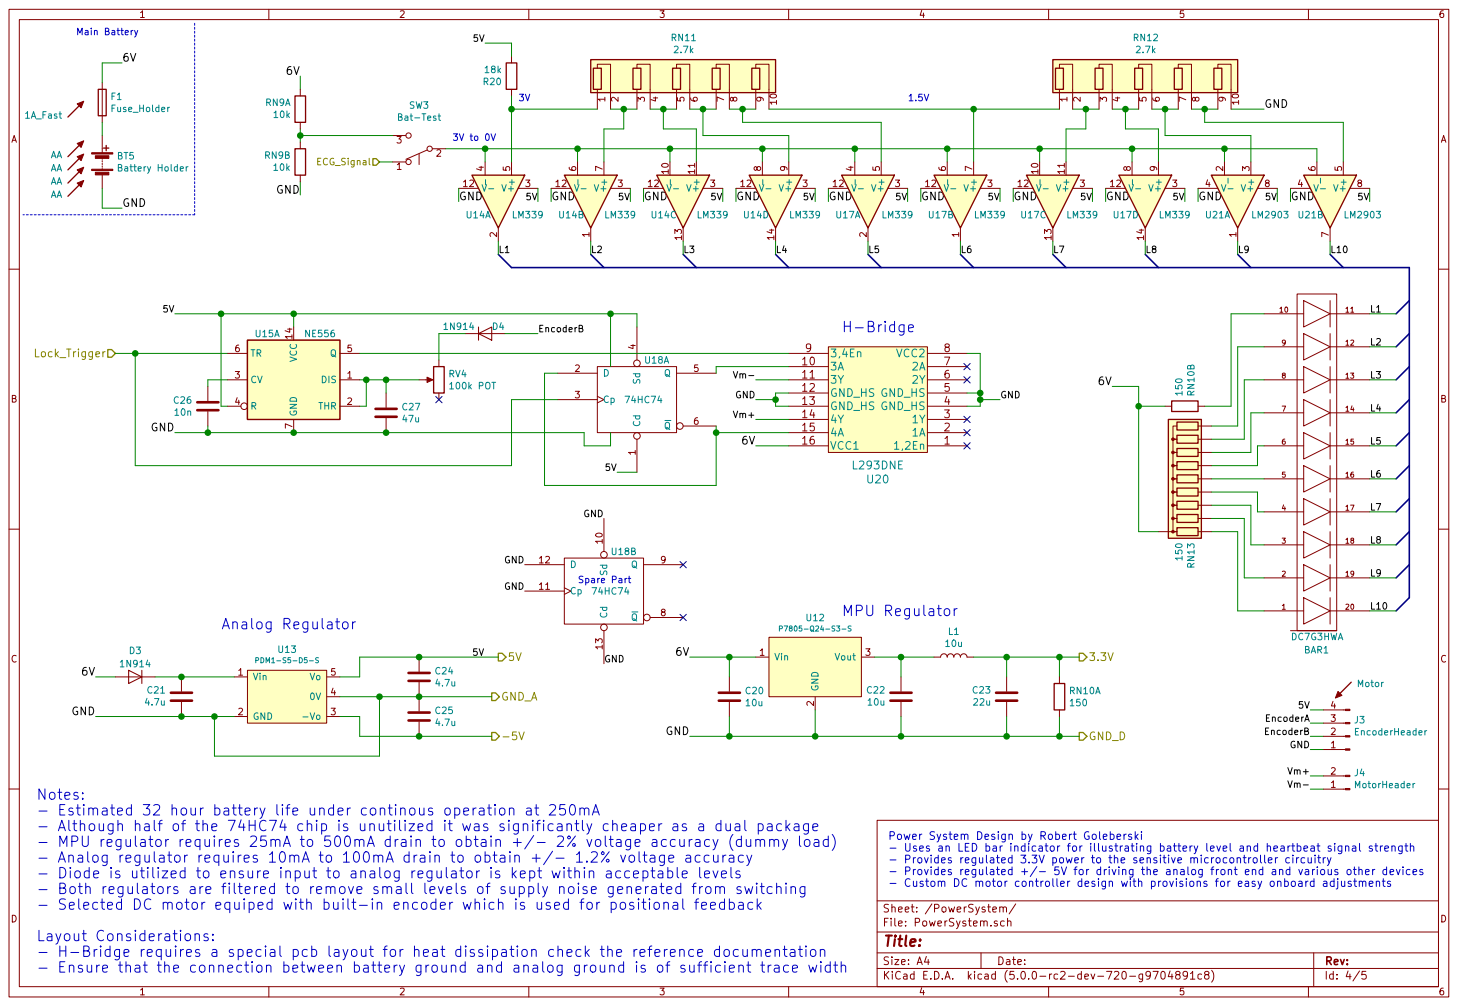
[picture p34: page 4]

7 VCC 14 DIS 1 THR 2 CV 3 R

Notes:
- Estimated 32 hour battery life under continous operation at 250mA
- Although half of the 74HC74 chip is unutilized it was significantly cheaper as a dual package
- MPU regulator requires 25mA to 500mA drain to obtain +/- 2% voltage accuracy (dummy load)
- Analog regulator requires 10mA to 100mA drain to obtain +/- 1.2% voltage accuracy
- Diode is utilized to ensure input to analog regulator is kept within acceptable levels
- Both regulators are filtered to remove small levels of supply noise generated from switching
- Selected DC motor equiped with built-in encoder which is used for positional feedback
Layout Considerations:
- H-Bridge requires a special pcb layout for heat dissipation check the reference documentation
- Ensure that the connection between battery ground and analog ground is of sufficient trace width

Power System Design by Robert Goleberski
- Uses an LED bar indicator for illustrating battery level and heartbeat signal strength
- Provides regulated 3.3V power to the sensitive microcontroller circuitry
- Provides regulated +/- 5V for driving the analog front end and various other devices
- Custom DC motor controller design with provisions for easy onboard adjustments

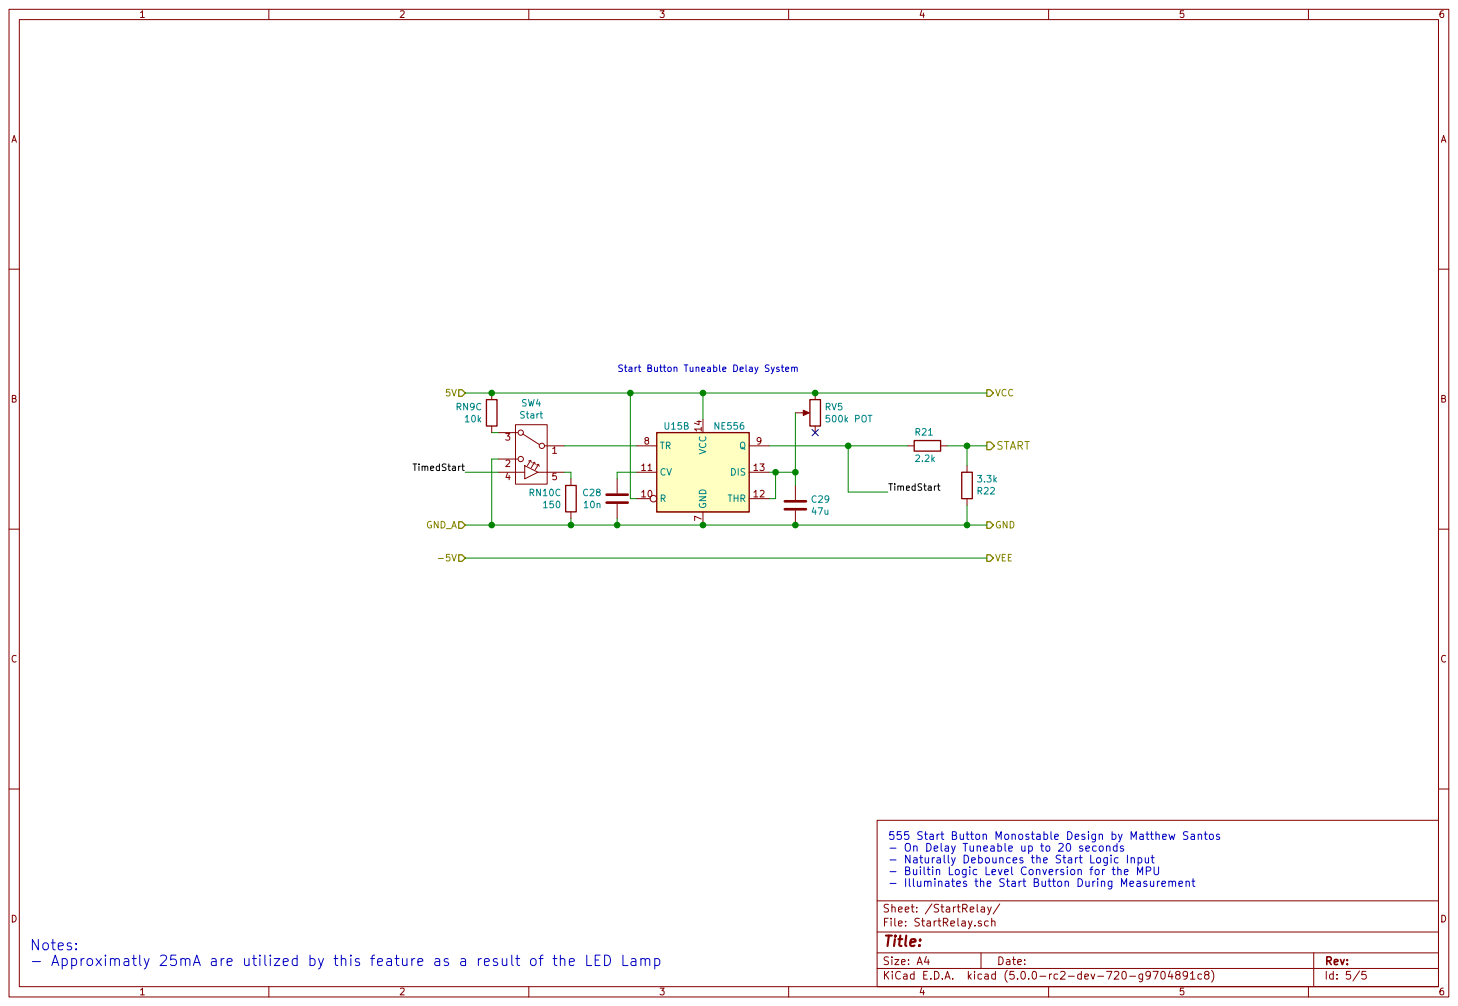
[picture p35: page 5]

- Illuminates the Start Button During Measurement GND

- On Delay Tuneable up to 20 seconds
- Naturally Debounces the Start Logic Input
- Builtin Logic Level Conversion for the MPU

- Approximatly 25mA are utilized by this feature as a result of the LED Lamp

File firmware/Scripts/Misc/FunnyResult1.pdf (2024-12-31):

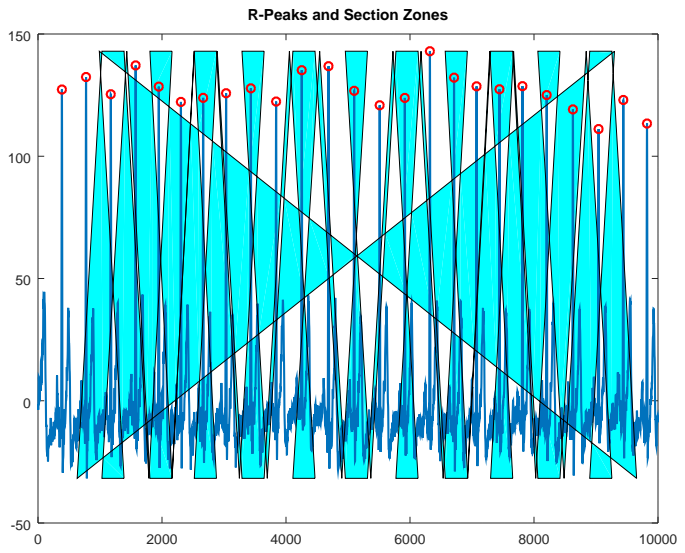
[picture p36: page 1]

R-Peaks and Section Zones

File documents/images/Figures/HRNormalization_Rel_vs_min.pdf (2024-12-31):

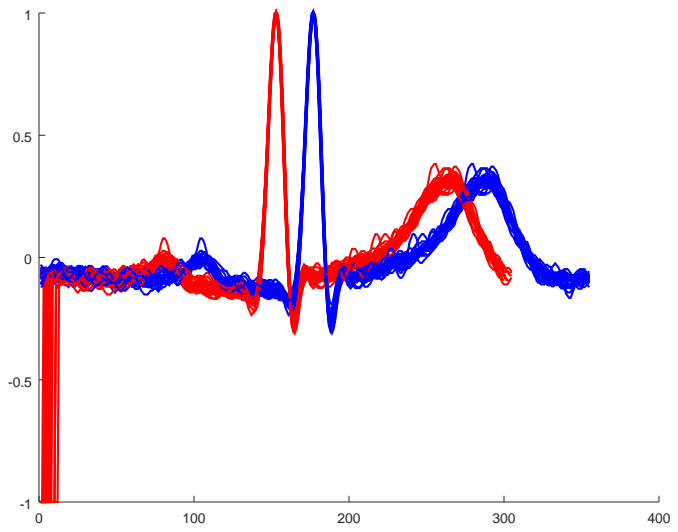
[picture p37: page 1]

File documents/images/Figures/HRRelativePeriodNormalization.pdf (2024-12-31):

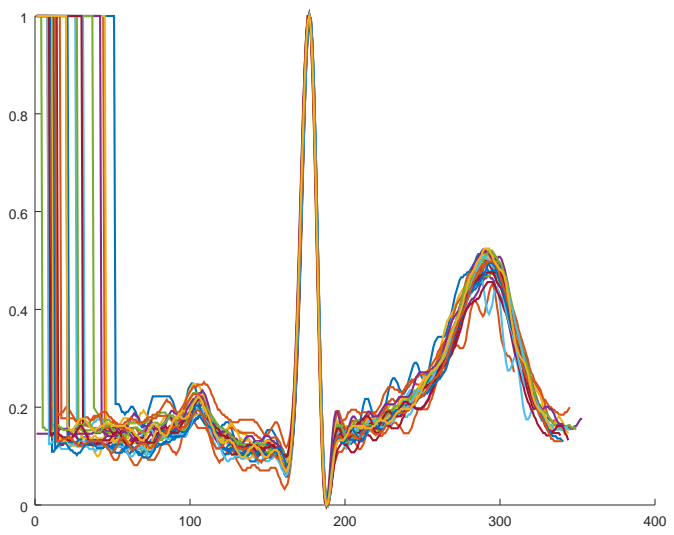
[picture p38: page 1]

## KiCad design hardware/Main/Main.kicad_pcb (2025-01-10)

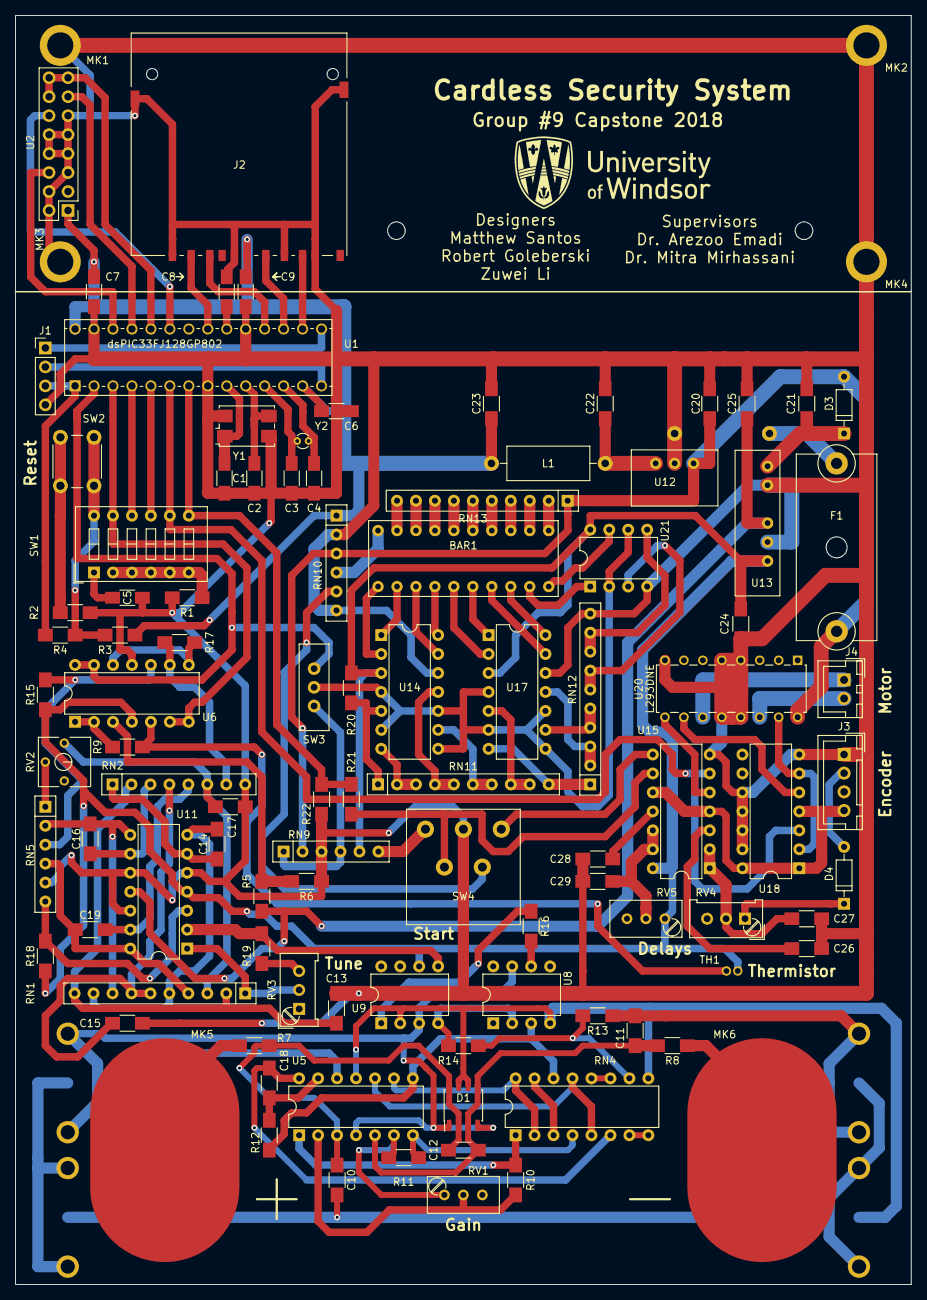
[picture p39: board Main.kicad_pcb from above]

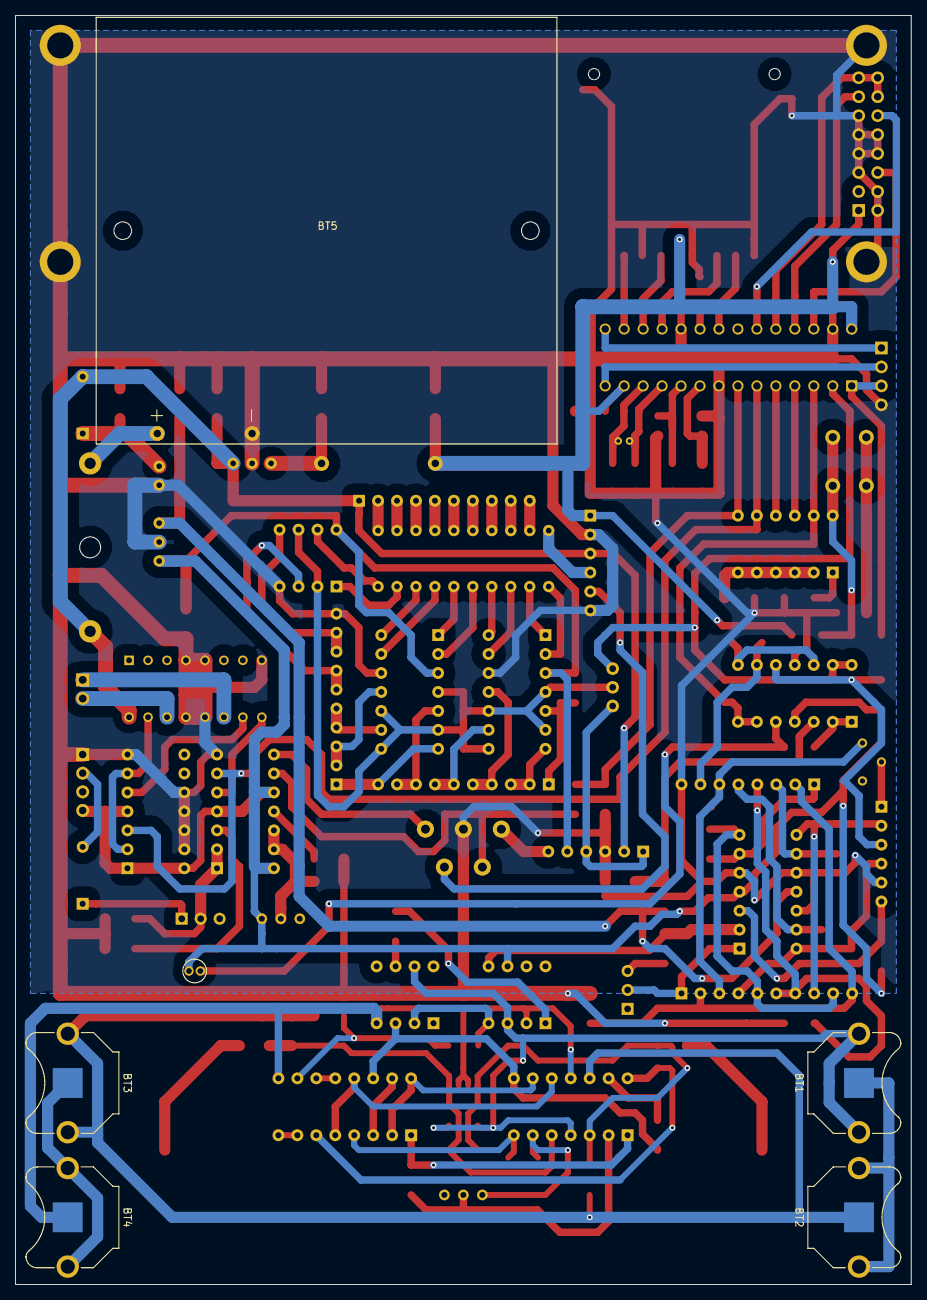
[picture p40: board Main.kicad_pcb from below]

Board: 2 copper layers, 120.0 x 170.0 mm, 108 parts (6 on the bottom side), 126 nets.

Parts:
BAR1: DC7G3HWA
BT1, BT2, BT3, BT4: Holder; Keystone_3001_1x12mm-CoinCell
BT5: Battery Holder; BH4AAPC
C1, C2: 27p; C1206C270F5GACTU
C3, C4: 15p; C1206C150J5GACTU
C5, C6, C7, C9: 0.1u; C1206C104K4RACTU
C8: 4.7u; F931C475KAA
C10, C11: 100p; R_1206_HandSoldering
C12: 1n; R_1206_HandSoldering
C13, C15, C17: 0.68u; R_1206_HandSoldering
C14, C16, C19: 0.068u; R_1206_HandSoldering
C18, C27, C29: 47u; R_1206_HandSoldering
C20, C22: 10u; R_1206_HandSoldering
C21, C24, C25: 4.7u; R_1206_HandSoldering
C23: 22u; R_1206_HandSoldering
C26, C28: 10n; R_1206_HandSoldering
D1: SMDA15TR; SOIC-8_3.9x4.9mm_Pitch1.27mm
D3, D4: 1N914; D_DO-35_SOD27_P7.62mm_Horizontal
F1: Fuse_Holder; 0031.8201
J1: ISCP; Pin_Header_Straight_1x04_Pitch2.54mm
J2: SD_Card; 145638009211859+
J3: EncoderHeader; JST_XH_B04B-XH-A_04x2.50mm_Straight
J4: MotorHeader; JST_XH_B02B-XH-A_02x2.50mm_Straight
L1: 10u; L_Axial_L11.0mm_D4.5mm_P15.24mm_Horizontal_Fastron_MECC
MK1, MK2, MK3, MK4: Mounting_Hole; MountingHole_2.5mm_Pad
MK5: Electrode_A; ECG_Pad
MK6: Electrode_B; ECG_Pad
R1, R4: 1k; R_1206_HandSoldering
R2, R16: 100; R_1206_HandSoldering
R3: 10k; R_1206_HandSoldering
R5: 5.6k; R_1206_HandSoldering
R6: 2.4k; R_1206_HandSoldering
R7, R8: 100k; R_1206_HandSoldering
R9: 3k; R_1206_HandSoldering
R10, R11, R19: 2k; R_1206_HandSoldering
R12: 82k; R_1206_HandSoldering
R13, R14: 1.5k; R_1206_HandSoldering
R15: 9k; R_1206_HandSoldering
R17: 40k; R_1206_HandSoldering
R18: 15k; R_1206_HandSoldering
R20: 18k; R_1206_HandSoldering
R21: 2.2k; R_1206_HandSoldering
R22: 3.3k; R_1206_HandSoldering
RN1: 3.3k; R_Array_SIP10
RN2: 10k; R_Array_SIP8
RN4: 10k; DIP-16_W7.62mm
RN5: 1k; R_Array_SIP6
RN9: 10k; R_Array_SIP6
RN10: 150; R_Array_SIP6
RN11, RN12: 2.7k; R_Array_SIP10
RN13: 150; R_Array_SIP10
RV1: 5kPOT; Potentiometer_Trimmer_Bourns_3296W
RV2: 3kPOT; 3362P-1-302LF
RV3: 2kPOT; Potentiometer_Trimmer_Bourns_PV36W
RV4: 100k POT; Potentiometer_Trimmer_Bourns_PV36W
RV5: 500k POT; Potentiometer_Trimmer_Bourns_3296W
SW1: SW_DIP_x06; 418117270906
SW2: Reset; TL1105F250Q
SW3: Bat-Test; EG1218
SW4: Start; UB15SKG035F-FF
TH1: Thermistor; DC103G9G
U1: dsPIC33FJ128GP802; DSPIC33FJ128GP802
U2: LCD_Header; Pin_Header_Straight_2x08_Pitch2.54mm
U5: LT1079CN; DIP-14_W7.62mm
U6, U11: TLC2264IN; DIP-14_W7.62mm
U8: LT1636; DIP-8_W7.62mm
U9: IL300; DIP-8_W7.62mm
U12: P7805-Q24-S3-S
U13: PDM1-S5-D5-S
U14, U17: LM339; DIP-14_W7.62mm
U15: NE556; DIP-14_W7.62mm
U18: 74HC74; DIP-14_W7.62mm
U20: L293DNE
U21: LM2903; DIP-8_W7.62mm
Y1: 10MHz; ABMM-10MHZ-B2-T
Y2: 32kHz; AB38T-32KHZ

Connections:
/AnalogFrontEnd/ECG_Signal: SW3.1, U1.2, U6.13, U6.14
/AnalogFrontEnd/GND_I: BT2.2, BT3.1, C10.2, C11.1, R13.2, U5.12
/AnalogFrontEnd/Isolator_Out: RN1.1, RV3.2, U11.1
/AnalogFrontEnd/Vcc_I: BT1.1, D1.1, D1.4, U5.4, U8.7, U9.3
/AnalogFrontEnd/Vee_I: BT4.2, D1.6, D1.7, RN4.9, U5.11, U8.4, U9.2
/MPU/AUX1: SW1.11, U1.3, U6.6, U6.7
/MPU/AUX2: SW1.10, U1.4
/MPU/AUX3: SW1.9, U1.5
/MPU/AUX4: SW1.8, U1.6, U15.6, U18.3
/MPU/LCD_CLK: U1.23, U2.12
/MPU/LCD_CS: U1.26, U2.6
/MPU/LCD_MISO: U1.25, U2.13
/MPU/LCD_MOSI: U1.24, U2.14, U2.15, U2.16
/MPU/PGC: J1.1, U1.15
/MPU/PGD: J1.2, U1.14
/MPU/PG_MCLR: J1.3, R4.1, U1.1
/MPU/SD_CLK: J2.5, U1.17
/MPU/SD_CS: J2.1, U1.21
/MPU/SD_MISO: J2.7, U1.16
/MPU/SD_MOSI: J2.2, U1.18
/MPU/START: R21.1, R22.2, SW1.7, U1.7
/PowerSystem/3.3V: C6.2, C7.1, C9.1, C23.2, J2.4, L1.2, R3.1, RN10.1, U1.13, U1.28, U2.1
/PowerSystem/6V: C20.1, D3.2, F1.1, RN9.2, RN10.3, RN13.1, U12.1, U20.16
/PowerSystem/-5V: C25.2, R5.1, U11.11, U13.3
/PowerSystem/EncoderB: D4.2, J3.2
/PowerSystem/L1: BAR1.11, U14.2
/PowerSystem/L2: BAR1.12, U14.1
/PowerSystem/L3: BAR1.13, U14.13
/PowerSystem/L4: BAR1.14, U14.14
/PowerSystem/L5: BAR1.15, U17.2
/PowerSystem/L6: BAR1.16, U17.1
/PowerSystem/L7: BAR1.17, U17.13
/PowerSystem/L8: BAR1.18, U17.14
/PowerSystem/L9: BAR1.19, U21.1
/PowerSystem/L10: BAR1.20, U21.7
/PowerSystem/Vm+: J4.2, U20.14
/PowerSystem/Vm-: J4.1, U20.11
/StartRelay/TimedStart: R21.2, SW4.4, U15.9
GND: BT5.2, C1.1, C2.1, C3.1, C4.1, C5.2, C6.1, C7.2, C8.2, C9.2, C13.2, C15.2, C17.2, C20.2, C21.1, C22.1, C23.1, C24.2, C25.1, C26.2, C27.2, C28.2, C29.2, J1.4, J2.3, J2.6, J2.8, J2.9, J2.12, J2.13, J3.1, MK1.1, MK2.1, MK3.1, MK4.1, R1.2, R2.2, R6.2, R22.1, RN2.8, RN5.5, RN9.3, RN10.2, RN10.6, RN12.10, SW4.2, U1.8, U1.19, U1.27, U2.2, U2.4, U2.5, U2.7, U2.8, U2.9, U2.10, U2.11, U6.11, U11.5, U11.10, U11.12, U12.2, U13.2, U13.4, U14.12, U15.7, U17.12, U18.7, U18.10, U18.11, U18.12, U18.13, U20.4, U20.5, U20.8, U20.12, U20.13, U21.4, Y1.2, Y1.4
unnamed: BAR1.1, RN13.2
unnamed: BAR1.2, RN13.3
unnamed: BAR1.3, RN13.4
unnamed: BAR1.4, RN13.5
unnamed: BAR1.5, RN13.6
unnamed: BAR1.6, RN13.7
unnamed: BAR1.7, RN13.8
unnamed: BAR1.8, RN13.9
unnamed: BAR1.9, RN13.10
unnamed: BAR1.10, RN10.4
unnamed: BT1.2, BT2.1
unnamed: BT3.2, BT4.1
unnamed: BT5.1, F1.2
unnamed: C1.2, U1.9, Y1.1
unnamed: C2.2, U1.10, Y1.3
unnamed: C3.2, U1.11, Y2.1
unnamed: C4.2, U1.12, Y2.2
unnamed: C5.1, SW1.1
unnamed: C8.1, U1.20
unnamed: C10.1, C12.1, D1.2, D1.8, R7.1, U5.3
unnamed: C11.2, C12.2, D1.3, D1.5, R8.1, U5.5
unnamed: C13.1, RN1.2, RN1.10, RN2.2
unnamed: C14.1, RN2.1, U11.6
unnamed: C14.2, RN1.5, RN1.9, U11.7
unnamed: C15.1, RN1.6, RN1.7, RN2.4
unnamed: C16.1, RN2.3, U11.9
unnamed: C16.2, RN1.8, RN5.2, U11.8
unnamed: C17.1, RN1.3, RN2.6, RV2.1
unnamed: C18.1, RN4.6, U5.14
unnamed: C18.2, R12.2, U5.13
unnamed: C19.1, RN2.5, U11.13
unnamed: C19.2, RN1.4, RN5.4, U11.14
unnamed: C21.2, D3.1, U13.1
unnamed: C22.2, L1.1, U12.3
unnamed: C26.1, U15.3
unnamed: C27.1, RV4.2, U15.1, U15.2
unnamed: C28.1, U15.11
unnamed: C29.1, RV5.2, U15.12, U15.13
unnamed: D4.1, RV4.1
unnamed: MK5.1, R7.2
unnamed: MK6.1, R8.2
unnamed: R1.1, SW1.2, SW1.3, SW1.4, SW1.5, SW1.6
unnamed: R2.1, SW2.1
unnamed: R3.2, R4.2, SW1.12, SW2.2
unnamed: R5.2, R6.1, U6.3
unnamed: R9.1, U6.1, U6.2
unnamed: R9.2, TH1.1, U6.5
unnamed: R10.1, RV1.2, U5.2
unnamed: R10.2, RN4.1, U5.1
unnamed: R11.1, RN4.4, U5.7
unnamed: R11.2, RV1.1, U5.6
unnamed: R12.1, RN4.14, U5.8, U8.3
unnamed: R13.1, R14.1, RN4.10
unnamed: R14.2, U8.2, U9.4
unnamed: R15.1, RN5.3, U6.10
unnamed: R16.1, U9.1
unnamed: R16.2, U8.6
unnamed: R17.1, RN2.7, U6.9
unnamed: R17.2, U6.8, U6.12
unnamed: R18.1, RN5.6, U11.3
unnamed: R19.1, RV3.3
unnamed: R19.2, U9.5, U11.2
unnamed: R20.1, RN11.1, U14.5
unnamed: RN4.7, RN4.8
unnamed: RN4.11, RN4.12
unnamed: RN4.5, RN4.13, U5.10
unnamed: RN4.3, RN4.15
unnamed: RN4.2, RN4.16, U5.9
unnamed: RN5.1, RV2.2
unnamed: RN9.1, RN9.4, SW3.3
unnamed: RN9.6, SW4.3
unnamed: RN10.5, SW4.5
unnamed: RN11.2, RN11.3, U14.7
unnamed: RN11.4, RN11.5, U14.11
unnamed: RN11.6, RN11.7, U14.9
unnamed: RN11.8, RN11.9, U17.5
unnamed: RN11.10, RN12.1, U17.7
unnamed: RN12.2, RN12.3, U17.11
unnamed: RN12.4, RN12.5, U17.9
unnamed: RN12.6, RN12.7, U21.3
unnamed: RN12.8, RN12.9, U21.5
unnamed: SW3.2, U14.4, U14.6, U14.8, U14.10, U17.4, U17.6, U17.8, U17.10, U21.2, U21.6
unnamed: SW4.1, U15.8
unnamed: U15.5, U20.9
unnamed: U18.2, U18.6, U20.15
unnamed: U18.5, U20.10
VCC: C24.1, J3.4, R15.2, R18.2, R20.2, RN9.5, RV5.1, TH1.2, U6.4, U9.6, U11.4, U13.5, U14.3, U15.4, U15.10, U15.14, U17.3, U18.1, U18.4, U18.14, U21.8

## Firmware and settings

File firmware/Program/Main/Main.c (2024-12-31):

// ECG Biometric Processor Code
// Written by Matthew Santos

/* Important Notes
  - No Watchdog
  - No Write Protection
  - Verify Overheat Protection (BrownOut thing)
  - Can potentially save pins by using SPI in Master/Slave Mode?
  - De-bounce the Start Button
*/

//Includes
#include "xc.h"         //Varriable Refrences
#include "Config.h"     //Configuration Settings
#include "Varriables.h" //Program Varriables
#include "Interrupts.h" //Interrupt Definitions
#include "Functions.h"  //Function Definitions

//Program Start

int main(void) {
    startup(); //Execute Startup Procedures
    while (1) {
        //Code Testing Area
        //------------------------------------

        
        //------------------------------------
        
        //Remove the Forced Status and Uncomment Sleep
        Status.start = 1;
        //Sleep();                  //Wait For Interrupt
        if(Status.start){           //Check if Start Was Pushed
            CollectData();          //Start Sampling
			Preprocessing();        //Start Preprocessing
            Sectioning();           //Start Sectioning
            FeatureExtraction();    //Start Feature Extraction
            FeatureNormalization(); //Perform Feature Normalization
            TestClassifiers();      //Use Support Vector Machine Sequentially
            authorizeCheck();       //Analyze Results
            LockReply();            //Perform Locking Action Based on Analysis
            Status.start = 0;       //clear start
        }
        else{
            Status.Error = 1;       //Error Since nothing else should wake the CPU
        }
    }
}

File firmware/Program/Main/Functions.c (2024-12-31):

// ECG Biometric Processor Functions
// Written by Matthew Santos

//Includes
#include "xc.h"         //Varriable Refrences
#include "dsp.h"        //DSP Library
#include "Varriables.h" //Program Varriables
#include "math.h"       //Math Functions
#include <libpic30.h>   //Compiler Helper Library
#include <string.h>     //String Functions
#include "fatfs/ff.h"   //SD-Card Filesystem Functions

//Function Definitions
//-----------------------

//Delay, causes CPU to pause for specified milliseconds [1,100000] limits
void Delay(int msec){
    __delay32(msec*40000);
}
int SQRT(int value){
    //w0 to w5
    //w4 = 0x4000
    //
    
    
    return value;
}
//startup, perform startup configuration on EVERYTHING!
void startup(){
  //Establish PLL Settings
  PLLFBD = 0x1E;            //M=32
  CLKDIVbits.PLLPRE = 0;    //N1=2
  CLKDIVbits.PLLPOST = 0;   //N2=2
  //Switch to HS External Clock Source
  __builtin_write_OSCCONH(0x3);    //Assign HS with PLL
  __builtin_write_OSCCONL(0x3);    //Maintain SOSC and Switch
  while(OSCCONbits.COSC != 3);     //Wait for HS Mode
  while(OSCCONbits.LOCK != 1);     //Wait for PLL Lock
  //Perform Global Management Tasks
  RCONbits.SWDTEN = 0;      //Disable Watch Dog Timer
  CORCONbits.US = 0;        //DSP Multiplies are Signed
  CORCONbits.IF = 0;        //Fractional Mode for DSP Engine
  CORCONbits.RND = 0;       //Unbiased Rounding Mode
  //Analog Pin Operating Mode (Not Listed => Digital)
  AD1PCFGLbits.PCFG0  = 0;  //Pin 2  => (Analog)
  AD1PCFGLbits.PCFG1  = 0;  //Pin 3  => (Analog)
  AD1PCFGLbits.PCFG2  = 1;  //Pin 4  => (Digital)
  AD1PCFGLbits.PCFG3  = 1;  //Pin 5  => (Digital)
  AD1PCFGLbits.PCFG4  = 1;  //Pin 6  => (Digital)
  AD1PCFGLbits.PCFG5  = 1;  //Pin 7  => (Digital)
  AD1PCFGLbits.PCFG12 = 1;  //Pin 23 => (Digital)
  AD1PCFGLbits.PCFG11 = 1;  //Pin 24 => (Digital)
  AD1PCFGLbits.PCFG10 = 1;  //Pin 25 => (Digital)
  AD1PCFGLbits.PCFG9  = 1;  //Pin 26 => (Digital)
  //Pin Directions (Not Used => Input)
  TRISAbits.TRISA0 = 1;     //Pin 2  => (Input)
  TRISAbits.TRISA1 = 1;     //Pin 3  => (Input)
  TRISBbits.TRISB0 = 1;     //Pin 4  => (Input)
  TRISBbits.TRISB1 = 0;     //Pin 5  => (Output)
  TRISBbits.TRISB2 = 0;     //Pin 6  => (Output)
  TRISBbits.TRISB3 = 1;     //Pin 7  => (Input)
  TRISAbits.TRISA2 = 1;     //Pin 9  => (Input)
  TRISAbits.TRISA3 = 1;     //Pin 10 => (Input)
  TRISBbits.TRISB4 = 1;     //Pin 11 => (Input)
  TRISAbits.TRISA4 = 1;     //Pin 12 => (Input)
  TRISBbits.TRISB5 = 1;     //Pin 14 => (Input)
  TRISBbits.TRISB6 = 1;     //Pin 15 => (Input)
  TRISBbits.TRISB7 = 1;     //Pin 16 => (Input)
  TRISBbits.TRISB8 = 0;     //Pin 17 => (Output)
  TRISBbits.TRISB9 = 0;     //Pin 18 => (Output)
  TRISBbits.TRISB10 = 0;    //Pin 21 => (Output)
  TRISBbits.TRISB11 = 0;    //Pin 22 => (Output)
  TRISBbits.TRISB12 = 0;    //Pin 23 => (Output)
  TRISBbits.TRISB13 = 0;    //Pin 24 => (Output)
  TRISBbits.TRISB14 = 1;    //Pin 25 => (Input)
  TRISBbits.TRISB15 = 0;    //Pin 26 => (Output)  
  //SD-Card Pin-outs (SPI-1)
  RPINR20bits.SDI1R = 7;    //RP7    => SD SPI-1 Data In
  RPOR4bits.RP8R = 8;       //RP8    => SD SPI-1 Clock
  RPOR4bits.RP9R = 7;       //RP9    => SD SPI-1 Data Out
  RPOR5bits.RP10R = 9;      //RP10   => SD SPI-1 Enable
  //LCD Pin-outs (SPI-2)
  RPOR6bits.RP12R = 11;     //RP12   => LCD SPI-2 Clock
  RPOR6bits.RP13R = 10;     //RP13   => LCD SPI-2 Data Out
  RPINR22bits.SDI2R = 14;   //RP14   => LCD SPI-2 Data In
  RPOR7bits.RP15R = 12;     //RP15   => LCD SPI-2 Enable
  //External Interrupts (Inputs)
  RPINR0bits.INT1R = 3;     //RP3    => INT-1 (START)
  //Digital Outputs (Outputs)
  RPOR0bits.RP0R = 0;       //RP0    => RP0   (AUX2)
  RPOR0bits.RP1R = 0;       //RP1    => RP1   (AUX3)
  RPOR1bits.RP2R = 0;       //RP2    => RP2   (AUX4)
  RPOR5bits.RP11R = 0;      //RP11   => RP11  (AUX5)
  //ADC-1 Configuration with DMA0 (CH0=AN1,CH1=AN0)
  AD1CON1bits.ADON = 0;     //Turn OFF ADC-1
  AD1CON1bits.ADSIDL = 1;   //Disable in Idle Mode
  AD1CON1bits.ADDMABM = 0;  //DMA Buffer in Gather Mode
  AD1CON1bits.AD12B = 0;    //10bit Operation
  AD1CON1bits.FORM = 3;     //Signed Fractional Operation
  AD1CON1bits.SSRC = 2;     //Conversion Rate Tied to Timer3
  AD1CON1bits.SIMSAM = 1;   //Simultaneous Channel Sampling
  AD1CON1bits.ASAM = 1;     //ADC Auto Sampling
  AD1CON1bits.SAMP = 1;     //Set ADC Pins to Sampling
  AD1CON2bits.VCFG = 0;     //Set Analog References to AVdd and AVss
  AD1CON2bits.CSCNA = 0;    //Disable Channel Scanning
  AD1CON2bits.CHPS = 1;     //Convert CH0 and CH1
  AD1CON2bits.SMPI = 1;     //Increment DMA Address after every 2nd sample
  AD1CON2bits.BUFM = 0;     //16-word Buffer Conversions
  AD1CON2bits.ALTS = 0;     //MUXA Input Selection
  AD1CON3bits.ADRC = 0;     //ADC Conversion Clock set to Program Clock
  AD1CON3bits.SAMC = 31;    //Sampling Time is ADC Program Clock x31
  AD1CON3bits.ADCS = 30;    //Conversion Time is Program Clock x31
  AD1CON4bits.DMABL = log(ADC1_BufferSize)/log(2); //Words of Buffer Per Input Per DMA Request
  AD1CHS123bits.CH123SA = 0;//CH1 = AN0
  AD1CHS123bits.CH123NA = 0;//Use AVss as Negative Reference
  AD1CHS0bits.CH0SA = 1;    //AN1 is CH0 Positive Input
  AD1CHS0bits.CH0NA = 0;    //Use AVss as Negative Reference
  IFS0bits.AD1IF = 0;		//Clear the ADC1 interrupt flag bit
  IEC0bits.AD1IE = 0;		//Do Not Enable ADC1 interrupt 
  DMA0CONbits.CHEN = 0;     //DMA CH0 Disabled
  DMA0CONbits.SIZE = 0;     //Set to Word Transfer
  DMA0CONbits.DIR = 0;      //Read from Peripheral to SRAM
  DMA0CONbits.HALF = 0;     //Initiate DMA Interrupt when all data written
  DMA0CONbits.NULLW = 0;    //Normal Operation, no write back
  DMA0CONbits.AMODE = 2;    //Use Peripheral Indirect Addressing
  DMA0CONbits.MODE = 2;     //Continuous Ping-Pong Mode
  DMA0REQbits.IRQSEL = 13;  //Use ADC-1 Peripheral
  DMA0CNT = 2*ADC1_BufferSize;  //Number of samples in DMA request
  DMA0STA = __builtin_dmaoffset(DMA0_BufferA); //BufferA Address
  DMA0STB = __builtin_dmaoffset(DMA0_BufferB); //BufferB Address
  DMA0PAD = (volatile unsigned int)&ADC1BUF0;  //Grab Data from ADC1BUF0
  IFS0bits.DMA0IF = 0;      //Clear DMA Interrupt Flag bit
  IEC0bits.DMA0IE = 1;      //Enable DMA CH0 Interrupts
  DMA0CONbits.CHEN = 1;     //Enable DMA CH0
  T3CONbits.TON = 0;        //Stop Timer 3 operation
  T3CONbits.TGATE = 0;      //Disable Gated Mode
  T3CONbits.TCKPS = 2;      //Pre-scaler 1/64
  TMR3 = 0x0000;            //Reset Timer 3
  PR3 = 40E6/64/sampleRate; //Define ADC Trigger Frequency
  T3CONbits.TSIDL = 1;      //Disable Timer 3 in idle mode
  IFS0bits.T3IF = 0;        //Clear Timer 3 Interrupt flag
  IEC0bits.T3IE = 0;        //Disable Timer 3 Interrupt
  T3CONbits.TON = 1;        //Start Timer 3 operation
  //SPI-1 Configuration (SD-Card)
  SPI1STATbits.SPIEN = 0;	//Disable SPI-1
  SPI1STATbits.SPISIDL = 1;	//Disable Operation in Idle Mode
  SPI1CON1bits.MODE16 = 0;  //Byte Communication
  SPI1CON1bits.MSTEN = 1;   //MasterMode ON
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

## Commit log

2024-12-31 feat: add primary content
    [AnalogFrontEnd.kicad_sch, BOM.ods, Beta_Calculations.ods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]
2025-01-10 fix: remove redundant gerber pdfs
2025-01-10 fix: error with pcb
    [Main.kicad_pcb]
